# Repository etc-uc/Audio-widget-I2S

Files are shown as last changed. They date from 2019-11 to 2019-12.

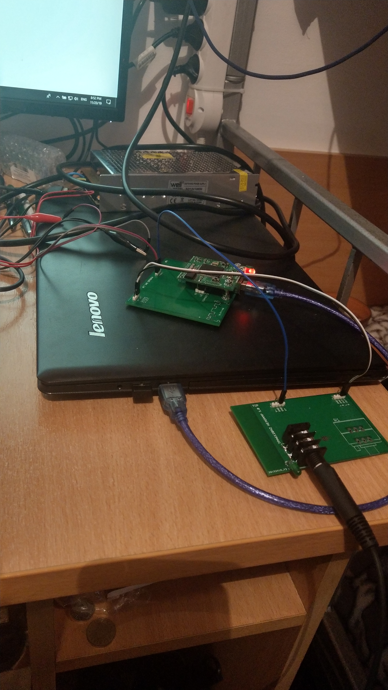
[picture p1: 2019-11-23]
IMAG1209.jpg

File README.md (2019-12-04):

# Audio-widget-I2S
**Interfata audio USB utilizand un AVR32 pe protocolul I2S**

## Introducere
>
>Inca din timpurile dinaintea erei digitale, consumatorii de audio **asa zisii audiofili** au fost in cautare de metode pentru reducerea la minim a distorsiunilor transmise catre difuzoare,si implicit,percepute de urechea umana.In vremea respectiva,data fiind si complexitatea destul de redusa a dispozitivelor,ideea reducerii distorsiunilor in sisteme era destul de limitata de topologiile propuse,de aceea aparitia sistemelor digitale de procesare in audio a dus la reducerea drastica a neajunsurilor semnalelor analogice.Pentru **puristi** , circuitele digitale si DSP-urile sunt considerate _un sacrilegiu_ adus audiofiliei,dar este unul justificat,deoarece in ciuda complexitatii mai ridicate fata de un circuit analog pur , sistemele digitale sunt mult mai eficiente fata de complementele sale,iar posibilitatea customizarii lor este foarte mare (spre deosebire de un circuit analogic unde,pentru a modifica o caracteristica trebuie regandit tot circuitul,in cazul unui circuit digital cu uC este doar o problema de software).

>Aparitia interfetelor audio s-a facut odata cu dezvoltarea PC-urilor si inregistrarea de muzica/sunete pe medii digitale , in pofida benzilor magnetice si a discurilor de vinil , deoarece era necesara o metoda de redare a sunetelor stocate pe calculatoarele vremii. De altfel,primele asa zise **placi de sunet** si-au facut aparitia prin calculatoare in jurul generatiei 80486 , cand deja exista o oarecare structura de operare stabila pe 16 biti , iar pentru o esantionare simpla a sunetelor erau arhisuficiente instructiunile implementate de Intel in procesoarele respective.
>>_Daca facem referinta la vremurile actuale,se poate spune ca practic nici nu se punea problema de calitate sau termenul de **Hi-Fi** in acele vremuri,dar acele sunete au reprezentat ceea ce urma sa fie boom-ul erei digitale_
>
>Ca si istorie a acestei ere in care traim,se pot scrie foarte multe lucruri deja cunoscute,asa ca voi incerca sa ma concentrez pe esential.

>Ideea de "calitate audio" pe digital a aparut in momentul lansarii pe piata mondiala a CD-ului (acel lucru care acum multora dintre noi ni se pare atat de outdated,ori chiar nu il mai folosim),dar el a avut cea mai mare influenta in aparitia de tehnologii de compresie si codare audio.Ca si concept,ideea de CD a aparut prin anul 1980 ,cand Philips si Sony au incheiat un parteneriat de cercetare in domeniul digital,dorindu-se un mediu de stocare unic transmisibil,care sa aibe un spatiu de stocare a informatiilor mult mai mare decat cel al dischetelor "floppy" si al benzilor magnetice,dar totusi sa nu coste cat un hard disk al vremurilor (memo: un hard disk de tip Winchester avea o capacitate de maxim 128MB , cantarea in jur de 15-20kg si era cam cat un desktop SFF actual ca dimensiuni si costa in jur de ~5.000 de dolari unul?).
>>Standardul CD a fost definitivat in jurul anului 1983,iar in urma intelegerii realizate intre cele 2 concerne se va realiza trecerea industriei audio catre acest mediu.

>Se pune problema "compresiei audio".In a nutshell,algoritmul de compresie audio se refera la un standard de scriere-redare a sunetelor pe calculatoare. Calculatoarele,la momentul respectiv avand sisteme de operare stabile precum UNIX si DOS (vorbind de anii '80,dar regula se aplica si in prezent pe sistemele actuale),pentru a reda sunetele stocate pe medii precum hard-diskul se folosesc de niste software numite **codec** .
>>Codecurile,in esenta,sunt niste pseudo-drivere pe care sistemul de operare le interpreteaza atunci cand se executa in sistem un fisier cu extensia ce corespunde codecului respectiv.
>>Adica,spre exemplu, avem un fisier cu extensia ".mp3" , SO va sti ca la instantierea acestui fisier va trebui sa apeleze un Codec LAME(Lame Ain't an MP3 Encoder - care este o derivatie imbunatatita de-a lungul anilor de diversi programatori din conceptul original gandit de institutul Fraunhofer din Germania).

>De altfel , toate procedeele de redare/compresie si extensiile de sistem au fost posibile datorita codarii PCM (Pulse Code Modulation).
PCM reprezinta transformarea semnalelor analogice in semnale digitale printr-un algoritm de esantionare constanta a amplitudinii semnalului analogic ,iar fiecare esantion este cuantizat la cea mai apropiata valoare dintr-o gama de cuante apropiate.
>>**Codarea PCM prezinta 2 proprietati ce determina calitatea conversiei semnalului original raportat la acesta : rata de esantionare a semnalului si _bit depth_,care reprezinta cantitatea de biti al fiecarui esantion realizat (un CD-Audio prezinta un bit depth de 16 biti per esantion , pe cand un Blu-ray sau DVD-Audio 24 de biti per esantion).**
>>> Extensiile posibile unei compresii PCM sunt ".wav" ,".L16",".PCM",".AIFF",".AU"

>Pe baza codarii/compresiei PCM a fisierelor audio, cei de la Philips au realizat in anul 1986 (si ulterior revizuit in 1996) un protocol de transmisie seriala al datelor audio intre dispozitive / circuite integrate , protocol care inca se foloseste cu succes si in prezent in dispozitivele audio. Este cunoscut sub acronimul I2S sau IIS **Inter-IC Sound** si se bazeaza pe o magistrala sincrona de transmisie de date (clockul de transmisie intre circuite este separat de magistrala de date,deci implicit receptorul nu mai are nevoie de un circuit suplimentar de refacere a frontului de ceas trimis de emitator).
>Protocolul este relativ usor de interpretat, in principal avem de-a face cu 3 semnale : bit clock line(**BCLK**) , word clock line (cunoscut sub denumirea oficiala de 'word select' **WS** sau 'left-right clock' **LRCLK** ) si cel putin o linie de date multiplexata **SD**

>>Adeseori se mai poate intalni peste cele 3 semnale cunoscute inca un semnal de tact (care nu face parte din protocol) cu rolul de a sincroniza operatiile interne ale DAC-urilor cu cele ale controllerului . Este gasit sub acronimul de "Master clock" **MCLK**
>>>Frecventa tipica de lucru se calculeaza dupa formula : **MCLK = 256 * LRCLK**

500px-I2S_Timing svg

###### Cum functioneaza protocolul:

>Semnalul de "Word Select" permite dispozitivului receptor sa 'vada' ce canal urmeaza sa fie trimis , deoarece I2S permite ca pe aceeasi linie de date sa fie trimise 2 canale,fiind un semnal cu factor de umplere 50% si frecventa egala cu cea de esantionare a semnalului trimis.
>>**Pentru semnale stereo , in brosura de specificatii a I2S se spune ca semnalul audio de pe canalul stang se transmite pe palierul de 0 al Word Select , iar canalul drept pe palierul de 1 . De obicei , semnalul "Word Select" este sincronizat dupa fronturile cazatoare ale semnalului BCLK , deoarece datele sunt zavorate pe fronturile crescatoare**.
>>
>Se stabileste semnul liniei de date si se codeaza in complement fata de 2 cu primul bit MSB-ul . **Acest lucru permite ca numarul de biti per cadru sa fie arbitrar , fara a fi nevoie de "negociere" intre emitator si receptor **.

## Specificatii montaj:

1.
 a)Microcontroller utilizat:  Atmel AT32UC3A3256 
 >>>  A complete system-on-chip 32-bit AVR microcontroller. It is designed for cost-sensitive embedded applications that require low power consumption, high code density and high performance.

 >>> The microcontroller's Memory Protection Unit (MPU) and fast, flexible interrupt controller support the latest real-time operating systems. Higher computation capabilities are achievable using a rich set of DSP instructions. The device incorporates on-chip flash and SRAM memories for secure and fast access. 64 KBytes of SRAM are directly coupled to the 32-bit AVR UC3 for performance optimization. Two blocks of 32 Kbytes SRAM are independently attached to the high speed bus matrix for real ping-pong management.

 >>> The microcontroller achieves exceptionally high data throughput by combining the multi-layered 32-bit AVR databus,128 KB on-chip SRAM with triple high speed interfaces, multi-channel peripheral, memory-to-memory DMA controller, high-speed USB embedded host, SD/SDIO card, MLC NAND flash with ECC, and SDRAM interfaces.

 >>> This device features 256KB internal high-speed flash and full-duplex multi-channel I2S audio interface.
 
 b) DAC utilizat: PCM5102A

 >>>The PCM510xA devices are a family of monolithic CMOS-integrated circuits that include a stereo digital-to-analog converter and additional support circuitry in a small TSSOP package. The PCM510xA devices use the latest generation of TI’s advanced segment-DAC architecture to achieve excellent dynamic performance and improved tolerance to clock jitter.

 c) Amplificator/buffer iesire folosit : TPA6120
 >>>In applications requiring a high-power output, very high fidelity headphone amplifier, the TPA6120A2 replaces a costly discrete design and allows music, not the amplifier, to be heard. The TPA6120A2’s current-feedback AB amplifier architecture delivers high bandwidth, extremely low noise, and up to 128dB of dynamic range.
 
2.Utilizeaza USB Audio Class 1 / 2.

3.Capabilitati de redare audio pana la 24bit/96kHz (bit depth / sampling rate).

4.Tensiune de alimentare: 5V (doar daca utilizam DAC-ul si interfata I2S) , +12/-12V (daca se utilizeaza si amplificatorul final)

5.Consum max: 1-1,5A (este necesara alimentare suplimentara deoarece amplificatorul final de casti se alimenteaza diferential) 

### Constructie montaj:

Contructia se bazeaza pe un design modular , iar in acest sens voi concepe intregul sistem pe 4 placi:
 - una o va constitui interfata emulatoare usb-i2s
 - o placa pentru DAC si , eventual , buffere de iesire
 - o placa pentru amplificatorul final
 - o placa pentru alimentare suplimentara

Ideea conceperii montajului intr-un sistem modular este pentru imbunatatirea "lantului" pe decursul timpului (ex. realizarea unui DAC mai performant din perspectiva SNR / PSRR sau schimbarea unei surse liniare cu una in comutatie sau adaugarea de acumulatori pentru portabilitate etc.)

De altfel,un montaj modular poate presupune o asezare mai buna in cutie si,totodata, un ecranaj mai bun al partilor **mai sensibile** fata de circuitul de alimentare.
IMAG1202
IMAG1204
IMAG1206

#### Particularitate software:

Ideea interfetei I2S este bazata pe un proiect deja existent in mediul online , anume SDR-Widget https://github.com/borgestrand/sdr-widget

Asadar hardware-ul din spatele acestui sistem a fost dezvoltat in asa fel incat firmware-ul cu care am programat AVR-ul sa fie direct compatibil.
Din punct de vedere functional, din software-ul dezvoltat in acel proiect am folosit doar mediul de comunicare audio via USB (UAC1 si UAC2) si partea de control software a volumului.

Consider ca nu este necesar sa uploadez toate sursele C pentru generarea firmware-ului , asa ca voi atasa fisierul HEX(.elf) continand versiunea stabila de firmware pentru acest sistem.

#### Programarea microcontrollerului:

Seria UC3A3 de la Atmel(Microchip-ish or whatsoever) au incarcate din fabricatie un bootloader ce contine un USB DFU(Device Firmware Upgrade).
DFU este un protocol ce se regaseste in orice tip de terminal ce are propriul sistem de operare,deoarece faciliteaza operatiunea de rescriere a software-ului deja setat in terminalul respectiv utilizand o interfata de comunicare uzuala.

De aceea , microcontrolerul pe care l-am utilizat in montaj (AT32UC3A3256) l-am programat cu doar un USB si programul ATMEL FLIP 3.4.7 , utilizand din acesta batchisp-ul (pentru ca,prin constructia sa , programul Flip nu suporta la un nivel stabil aceasta serie de uC-uri).




Nu mai pot reproduce inca o data procesul de programare (sau il voi mai face ulterior daca dezvolt un alt firmware mai performant pentru cerinta data), dar comanda de programare pe care am utilizat-o este:
**batchisp -device at32uc3a3256 -hardware usb -operation erase f memory flash blankcheck loadbuffer widget.elf program verify start reset 0**
Unde widget.elf se inlocuieste cu denumirea HEX-ului de urcat pe uC.

Dupa introducerea comenzii se executa programarea uC-ului in 11 pasi:

AT32UC3A3256 - USB - USB/DFU

Device selection....................... PASS

Hardware selection..................... PASS

Opening port........................... PASS

Reading Bootloader version............. PASS    1.0.3

Erasing................................ PASS

Selecting FLASH........................ PASS

Blank checking......................... PASS    0x00000 0x3ffff

Parsing ELF file....................... PASS    widget.elf

WARNING: The user program and the bootloader overlap!

Programming memory..................... PASS    0x00000 0x1c43f

Verifying memory....................... PASS    0x00000 0x1c43f

Starting Application................... PASS    RESET   0

Summary:  Total 11   Passed 11   Failed 0

Dupa programarea uC-ului calculatorul "teoretic" ar trebui sa il recunoasca automat si sa instantieze driverul necesar utilizarii acestuia. Cel putin in Windows 10 nu exista probleme de compatibilitate a driverelor, recunoscandu-le automat la conectarea interfetei. Posibil sa existe probleme de "backwards compatibility" a firmware-ului cu versiunile mai vechi de Windows,dar se rezolva instaland manual "inf drivers".

## Utilizare:

Asio_logo

Ca si software , interfata este gandita destul de simplist,deoarece se considera ca este suficient doar un control al volumului,niciun fel de egalizare grafica sau corectie de tonuri.
Software-ul de control este scris pe framework-ul ASIO (_Audio Stream Input-Output_).
Ca si un mic memo : ASIO este un protocol de drivere open-sourced pentru "sound card-uri" specificat in industria audio de firma Steinberg.
Ca si functionare a protocolului : ASIO produce un bypass al caii audio normale la nivel de aplicatie din sistemul de operare utilizat,astfel incat sa se evite "layer-ele" suplimentare la nivel de software.Acest lucru permite aplicatiei sa se conecteze la sound card direct,fara intermedierea sistemului de operare in procesul respectiv.Acest lucru duce la o reducere foarte mare a latentei de transfer a informatiei audio de la soft la hard.

Foobar2000_logo_2014

>>Foobar2000 **logo de mai sus** este un player audio freeware (nu este necesara licenta de utilizare) pentru Microsoft Windows, iOS, si Android dezvoltat de Peter Pawłowski.Ca si software este cunoscut designul sau extrem de modular , multitudinea de caracteristici si flexibilitatea in configurare pentru user.
>>Acest player suporta foarte multe formaturi audio , prezinta o multitudine de caracteristici organizarea fisierelor , metadata si are implementata o interfata de convertor utilizabila in linie de comanda (transcodare fisiere si ripping CD-Audio). 



In poza , aplicatia redand un fisier audio .FLAC (lossless audio codec) , configurat pentru output pe WASAPI* , buffer length minim pentru jitter scazut intre interfata de comunicare si controller.

>>>> **Ca si ASIO , WASAPI (Windows Audio Session API) este un plugin utilizat in audio pentru a permite trecerea fluxului de date audio direct intre terminalul audio din aplicatia ce reda fisierele audio**
>>>> Diferenta principala dintre ASIO si WASAPI este ca , primul este un plugin open-source (poate fi luat si modificat in drivere de oricine) , pe cand cel din urma este conceput de MICROSOFT si na...copyright in a nutshell daca vrea cineva sa modifice core-ul plugin-ului.



>>>Ca si comparatie intre cele 2 pluginuri, ambele sunt foarte usor de utilizat si instalat , cu precizarea ca ASIO functioneaza cu doar cu dispozitivele ce au descriptori dedicati in driverele lor , pe cand WASAPI functioneaza cu orice fel de endpoint device , atata timp cat este selectat pluginul ca si output pentru device-ul respectiv si nu adresa "Direct Sound".

>>>> **De precizat ar mai fi ca,atata timp cat un eveniment WASAPI / ASIO este executat , nu se mai reda niciun flow audio din partea altor aplicatii pana nu se incheie evenimentul respectiv**

### Ansamblare

Pentru incapsularea proiectului am ales sa separ sursa de alimentare de partea de DAC+Amplif casca pentru a evita producerea de zgomot inutil in sistem. **ideea este tocmai de a avea un zgomot minim in tot lantul si atunci este de preferat ca sursa sa stea cat mai departe de elementele sensibile ale sistemului**

Asadar , pentru incapsularea amplificatorului am comandat o carcasa din aluminiu eloxat argintiu de la Hammond,cu dimensiunile 220x103x31mm (LxlxH) , iar pentru sursa probabil voi utiliza o cutie de ramificatie electrica **de aparataj** pentru ca nu are prea mare importanta aspectul ei (ca oricare alta sursa de alimentare, va sta intr-un loc prea putin vizibil).



Pentru alimentare voi monta pe ambele carcase o mufa DIN 3P ce se asigura cu o piulita de blocare , cu 3 pini deoarece amplificatorul se alimenteaza diferential.

#### Masuri pentru evitarea producerii/captarii de zgomot in circuit:

1.Decuplarea alimentarilor cu condensatoare de valoare foarte mica (capabilitate de lucru in frecvente mari) - zeci/sute nF si de valoare f. mare (capabilitate de lucru in frcvente mici).

2.Torsadarea cablurilor de alimentare din carcasa (reducerea emisiilor em. in circuit).

3.Separarea pe cat posibil a circuitelor de semnal mic fata de cele de alimentare.

4.Utilizarea unui punct comun de legatura a maselor din intregul circuit (star pattern sau line pattern , in cazul meu voi utiliza un line pattern deoarece nu sunt implicati curenti mari de circuit - max 1A peak).

5.Utilizare de filtraj cat mai generos - capacitatile mari de filtrare implica un riplu foarte mic al sursei de alimentare,deci posibilitatea aparitiei unui zgomot perturbator pe alimentare minim.
>>Cu riscul aparitiei unui curent de incarcare foarte mare,se recomanda utilizarea de capacitati mari pentru evitarea riplului,mai ales in circuite unde este nevoie de curenti mari pe perioade scurte.
>>>Problema curentilor mari de incarcare se rezolva cu niste rezistente serie cu condensatorii (zeci de ohmi),care sa limiteze curentul prin ei la pornire,dupa aceea rezistentele se sunteaza cu un releu si se utilizeaza normal **soft-start empiric**

**RIPLU -> componenta alternativa aparuta la ciclurile de incarcare-descarcare ale condensatorilor intr-un redresor**

## Limitari si probleme aparute de-a lungul constructiei:

Cea mai mare problema am avut-o la ansamblare...un cosmar si jumatate din perspectiva unei persoane ce a lucrat mai tot timpul cu componente THT si acum s-a lovit de "zidul" lipirii de componente SMD. Am facut si prostia de a ma apuca si fix de cea mai complicata placa mai intai , cea a interfetei USB-I2S, cei 144 de pini ai uC-ului mi-au dat de furca pana l-am lipit cum trebuie,deoarece m-am incapatanat sa il lipesc pin cu pin cu letconul si la un moment dat aveam efectiv mai multe scurturi intre pini decat pini lipiti cum trebuie de placa.Dar acest mic detaliu a fost rezolvat cu mult flux,efect capilar si injuraturi cand nu voia fludorul sa plece dintre pini pe talpa varfului folosit.
De altfel ,toate componentele 0603 de pe aceasta placa mi-au provocat o mare placere de a invoca sfinti de-a lungul lipirii lor.
Apexul a fost atins la ora 3 noaptea,dupa ce am terminat de lipit placuta interfetei,am legat-o la USB si am realizat,cu stupoare,ca nu face nimic...nu se conecta la calculator.Din nou,nervi injuraturi,abtineri din a tranti minunea peste tot.
A doua zi am rezolvat problema in 10 minute : stabilizatorul 5V-3.3V de pe placa avea un pin " in aer " si nu aveam output pentru alimentarea uC-ului.

**Morala ar fi ca: prea multe beri si oboseala dupa 12 ore de alergat dintr-o parte in alta dauneaza bunei atentii asupra realizarii unui montaj.**

Montarea placii DAC a fost pretty straightforward , nu am intampinat cine stie ce dificultati, mai ales acum avand experienta lipirii "ghindoacelor" 0603 pe placa interfetei ... componentele 1206 si integratul SSOP cu 20 de pini au fost PARFUM!!

Placa amplificatorului am montat-o si cam atat, pana acum m-am folosit doar de mufa de casca pentru a vedea daca functioneaza dacul cum trebuie.Urmeaza sa montez si sursa de alimentare si o voi testa si pe aceasta.

Singura limitare "constructiva" mi-am creat-o singur,din pricina carcasei alese pentru circuit. Am ales o carcasa cu inaltimea de 31mm, insuficient pentru inaltimea potentiometrului pe PCB-ul amplificatorului.Am fAacut aceasta eroare deoarece nu am tinut cont ca primele caneluri de suport pentru cablaje incep de la aproximativ 5mm fata de fundul carcasei , ceea ce ar insemna ca depasesc inaltimea montarii capacului cu potentiometrul cu vreo 2mm din ce am masurat.

Solutia: montat potentiometrul si mufa de casca solitare pe panoul frontal si facut legaturi cu PCB-ul prin cabluri torsadate si mufate.

## Constructie sursa de alimentare

Cel mai mare semn de intrebare posibil din tot proiectul ce se putea pune : Ce sursa de alimentare sa folosesc , liniar sau comutatie? Cum naiba fac sa nu stric tot "zenul" montajului cu zgomote inutile aduse de catre o sursa?

De altfel, orice sursa as alege inevitabil tot ma aleg cu un oarecare zgomot in circuit,pentru ca nu poti elimina o cauza fara a genera un alt defect.

Solutia : **in mintea mea** 

Se da o sursa clasica stabilizata , realizata extern circuitelor de semnal / amplificat. Sursa o voi realiza cu un transformator incapsulat in rasina de 10-15VA,deoarece nu am nevoie de foarte multa putere de iesire. Redresare cu punte de diode clasise / schottky (inca nu m-am decis daca se merita efortul pentru diode schottky,mai ales pentru frecventa retelei).

Filtraj inainte de stabilizare 2x4700uF + decuplarile de rigoare pe diode cu 100nF + 220-470nF in bratul stabilizatorului + buffer suplimentar de curent dupa stabilizatoare 2x4700uF + 100nF. Bufferul il voi amplasa in carcasa interfetei,pentru a realiza si punctul comun de legatura al masei pentru tot circuitul.

Imi asum riscul ca voi avea un curent initial de incarcare enorm pentru acel transformator (10000uF insumati pot produce un oarecare deranj mai ales pentru o sursa ce nu debiteaza un curent foarte mare),dar acest lucru il voi vedea exact cand voi finaliza si acest pas.

Stabilizatoarele probabil vor fi clasicele 7812/7912 (not so many fancy things there , sursa trebuie sa fie cat mai simpla si eficienta,fara prea multe briz-briz-uri).

## Final updates

1. La indemnul tatalui meu am achizitionat inca o carcasa de la Hammond , "sora" celei pe care am prezentat-o mai sus , din pricina incapsularii tuturor modulelor intr-un singur loc si nu "in o mie si una de cutiute". Ca si forma sunt identice,singura diferenta o face inaltimea lor (31mm vs 53mm).

2. Am ansamblat sursa de alimentare *dupa lupte seculare as putea spune* si am descoperit ca pentru ce am eu nevoie 4700uF pe brat de alimentare este mai mult decat suficient.Dupa cum ma asteptam , folosind pattern-ul line pentru legarea maselor la comun si decuplarea "sanatoasa" a elementelor sursa nu induce zgomot in circuite...great succes i would say :)
Singura problema: am facut-o pe cablaj de test pentru ca nu am mai avut rabdare sa corodez o foaie de cablaj ... but not so much of a thing pentru ca am tinut cont de dimensionarea corecta a traseelor de circuit si pozitionarea elementelor disipatoare de caldura astfel incat circuitul sa nu se degradeze rapid,dar totusi sa fie compact si sa se incadreze in aria necesara.

3. Odata cu sursa,am testat intr-un final si amplificatorul final si pot spune ca a meritat asteptarea...chiar suna foarte bine in combinatie cu dacul facut.Imi era foarte teama de imperecherea lor,dar a fost doar paranoia si atat.

Dar credeti ca am scapat de peripetii? Nicio sansa, la prima "cheie" amplificatorul nu a vrut sa cante nici sa-l fi batut.
Am incercat sa elimin toate posibilele cauze , in prima instanta am inlocuit toate cablurile de legatura dar degeaba ca tot nu a vrut sa mearga. Am sucit sursa pe toate partile,am zis ca poate am legat ceva prost pe acolo,dar nicio sansa,toate legaturile erau facute bine si aveam tensiune aproape egala pe ambele brate de alimentare.Ce mama masii sa mai aiba si placa asta acum?!
Am legat dacul direct la iesirea de casti si aveam semnal redat,deci nicio sansa sa fie din alta parte problema.
Deschid schema , stau si ma uit la layoutul cablajului si dupa realizez ca integratul meu amplificator este montat invers pe pcb ... #$%^#$$@$^$%^#$#@%#$^ masii de treaba. Tuff job de dezlipit din cauza fludorului ce tine padul de disipatie termica lipit de cablaj.Din nou,sfinti,altare si tot tacamul pana l-am dezlipit si relipit (noroc cu colegul de camera muuuultt mai rabdator decat mine).
Dupa ce l-am relipit zeii siliciului au decis sa nu imi arda integratul si l-am putut auzi cantand, finally . Intr-un final , tot lantul meu audio este gata si functional, iar singurul lucru ce mi-a mai ramas de facut este sa gauresc panoul frontal si sa strang ultimele 4 suruburi de pe cutie :)

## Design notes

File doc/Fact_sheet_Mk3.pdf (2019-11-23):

Henry Audio

fact_sheet_Mk 3.pdf | BSB – 20180811
1

## 1. Introduction

This document is intended for everybody who wishes to use or investigate the Henry Audio USB DAC 128 Mk 3 and its predecessors (Henry Audio USB DAC 128 USB DAC 128 mk II, QNKTC AB-1.2, AB-1.1 and AB-1.0). The schematics for all these products are Open Source!

Programmers and developers should also read the complete project readme file at https://github.com/amontefusco/sdr-widget/blob/audio-widget-experimental/AW_readme.txt

For commercial reuse of the technology behind Henry Audio's products you should contact borge@henryaudio.com

The contents of this file are:

## 2. Technical Specifications

The USB DAC 128 Mk 3 plugs in between your computer and an audio amplifier. It will work on Linux, Mac and Windows. With a powered USB hub and an on-the-go cable it will also work on Android and iOS devices. High resolution audio is not guaranteed on Windows XP.

The electrical design focuses on high quality circuit board layout and good components.

Some technical details:

- A fully assembled, tested and packaged DAC which plays music out of the box
- Asynchronous USB Audio powered by Golledge high-quality crystal oscillators at 22.5792 and 24.576MHz
- Supports the common sample rates of 44.1, 48, 88.2, 96, 176.4 and 192ksps

Henry Audio

2

- RCA (phono) stereo outputs
- Asahi Kasei AKM4430 DAC
- Atmel AVR32 general-purpose MCU programmed in open source C
- ASIO driver for Windows programmed in open source C
- Low-noise 3.3V ADP151 LDOs powered from USB. No external power supply.
- The option of experimenting with the power supply.
- Lots of internal headers for experimenting.
- You must provide a USB 2.0 type-B cable. This is the same kind of cable as is typically used with a printer. It is not included. Use a cable shorter than 3m.
- Mechanical size: W: 114.4mm, H: 32.8mm, D: 119mm.
- Computer requirement: The DAC will work on well on all modern computers. The DAC may not work well on computers with processors below the performance of a Core 2-duo / 2GHz CPU. USB Audio Class 2 drivers may not work on Windows XP.

## 3. USB Audio Class 1 & 2

USB Audio has two different ways to communicate with the computer, USB Audio Class 1 and 2. The USB DAC 128 Mk 3 will operate in both UAC1 and UAC2.

The reason for supporting two modes is that only UAC1 is supported by all operating systems, including Windows.

UAC2 is needed for high resolution playback. Windows 10 supports UAC2. Earlier versions of Windows (7, 8, XP) need a special driver to work with UAC2. See the next sections of this document. When the DAC is first powered on it will use UAC1. That way it will work right out of the box on all computers, and the playback will have more than CD quality.

Windows 10, OS X, Linux, iOS and Android support both UAC1 and UAC2 natively. On those systems you may as well select UAC2 as you start using your new DAC.

UAC1 is more than enough if the music you play was once on a CD. The Henry Audio USB DAC 128 Mk 3 supports up to 24 bit / 48ksps in UAC1. That is more than sufficient for ripped CDs or streaming.

Henry Audio

3

UAC1 is indicated by a green light at the front of the USB DAC 128 Mk 3. UAC2 is indicated by a red light. To switch between the two modes do as follows:

- Press the rear Prog button until the light changes
- Keep pressing Prog until the light goes dark
- Press and release Reset

## 4. Asynchronous USB Audio

The USB audio protocol is asynchronous with both UAC1 and UAC2. That means the analog part of the DAC minimizes jitter errors.

What does asynchronous USB mean? It means the DAC is the timing master. In typical digital audio based on S/PDIF (coax) and TOSLINK (optical) cables the audio data and the clock are synchronous. Both travel from the same source. This source is typically a CD drive. Such a drive may or may not be made with a good internal clock circuit.

Synchronous digital audio is also common over USB. Then the timing reference is derived inside the computer. That clock is often very noisy. With synchronous digital audio the DAC is responsible for extracting the clock signal.

Instead, with an asynchronous protocol, the source of the audio data becomes the timing slave. Commands are sent on the USB cable from the DAC to tell the computer to speed up or slow down. This enables the DAC to use precision crystal oscillators instead of a complex clock regenerator. The audible result is that many of the typically digital artifacts are significantly reduced.

## 5. Disabling resampling

Most modern operating systems, except for iOS, will automatically resample your digital music as it is being played back. This is not a major issue, but it may improve sound quality to turn it off. Some player programs disable resampling on their own. On Windows using the protocols WASAPI or ASIO disables resampling.

Because most digital music is recorded at the CD's sample rate of 44.1ksps, you are recommended to set this as the default sample rate for the DAC.

Linux and MPD
If you use Linux and MPD make sure you enter the following line in the audio_output section of your .mpdconf file:
auto_resample "no"

Henry Audio

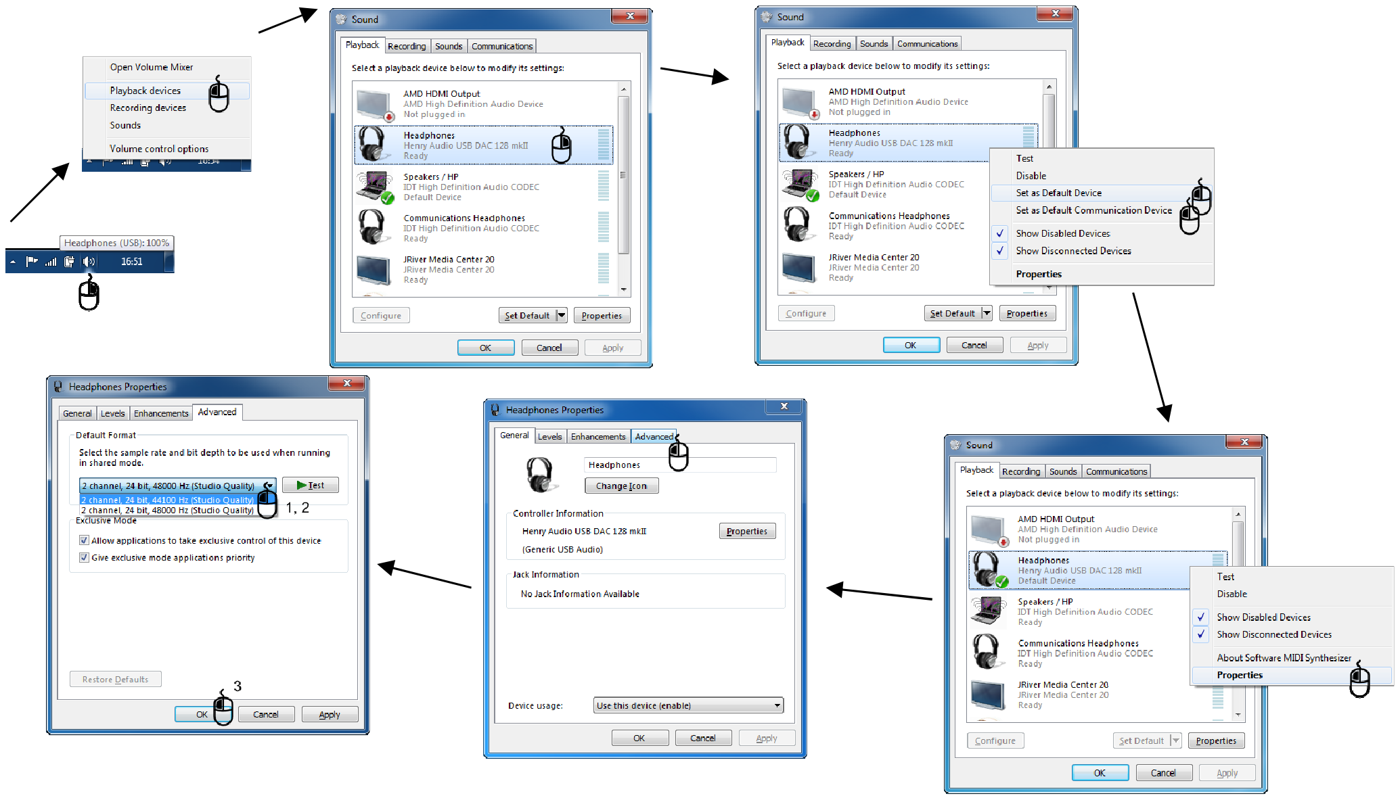
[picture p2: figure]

4

This will disable resampling, and you don't need to set a default rate.

OS X
In OS X the sample rate setting for a DAC is set in the "Audio MIDI Setup". Look for this icon under Applications, Utilities:

The 44.1ksps setting is the best way to use generic Mac programs to play back music which was once stored on a CD. It is also the recommended setting for streaming music from the internet.

For playback of hi-res material, make sure that your player program is able to override the sample rate setting of OS X.

NB: On your Mac you should set the default sample rate to 44.1ksps for both UAC1 and UAC2 configurations of the DAC. That is because your computer will recognize those as two different DACs.

Windows 7
On Windows you can only set the default sample rate to 44.1ksps when the DAC is in UAC1 mode. In UAC2 mode, with the ASIO driver, there is no need to do this. Follow these steps to set the sample rate:

Henry Audio

5

Windows 10
The menu structure in Windows 10 is slightly different:

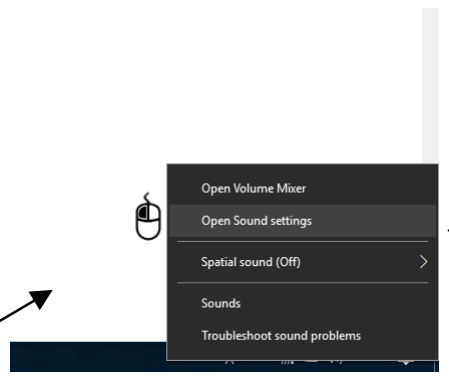
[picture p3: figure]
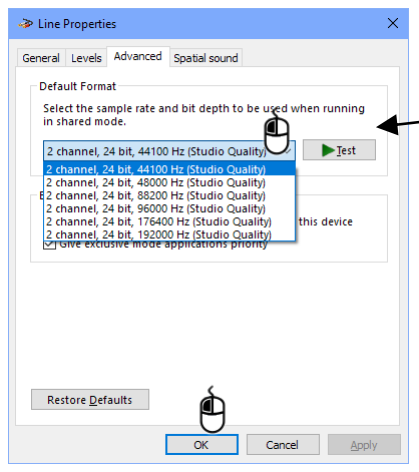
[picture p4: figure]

## 6. Installation on Windows

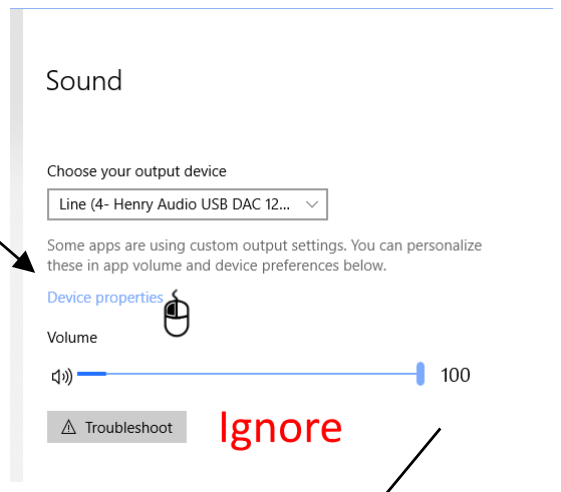
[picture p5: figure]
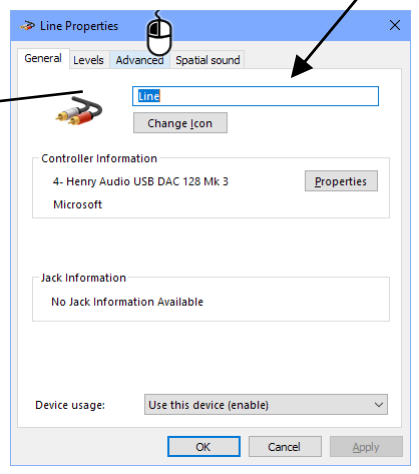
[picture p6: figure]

Windows 10 needs no special attention to make the DAC work for hi-res music. Both UAC1 and UAC2 drivers come pre-shipped with the operating system, and you can enjoy high resolution music from all Windows programs.

Do you use Windows 7 or Windows 8? In that case there is no built-in support for USB Audio Class 2, and you will have to choose between two ways to use the DAC:

Option 1: Use the DAC as it is delivered and listen to music at (or slightly above) CD quality from all Windows programs. To do this you need NO driver installation and NO button presses on the DAC.

Option 2: Use the DAC in USB Audio Class 2 mode with an ASIO driver. This option enables hi-res music and sample rates up to 192ksps on Windows 7 and Windows 8 computers. On these computers, such resolution is only available in ASIO enabled player programs. Please note: When used in UAC2 on Windows 7 and Windows 8, the DAC will NOT appear as an ordinary sound card.

Henry Audio

6

Follow these steps to install the hi-res ASIO driver for the USB DAC 128 Mk 3 on a Windows 7 or 8 computer. Windows XP functionality is not guaranteed.

1. Do not plug in the USB DAC 128 Mk 3 yet.

### 2. If you have an earlier version of the driver installed, first follow the uninstall

instructions later in this text.

### 3. Download and install the driver from

https://github.com/borgestrand/widget_binaries/blob/master/AWSetup_20130211.zip

### 4. Answer Yes and OK to all questions. You may have to approve that an

unsigned driver may be installed.

### 5. Put the DAC into UAC2 mode according to section 3. The first time you

change modes, Windows may have to install additional drivers. It should be able to do that fully automatically.

## 7. Setup with JRiver Media Center

The JRiver Media Center is a powerful media playback program. It offers a 30-day free use and after that must be paid for. The license cost is currently USD 50.

After following the steps on driver installation do as follows:

### 1. Download and install Media Center from http://www.jriver.com/download.html

### 2. Plug in the USB DAC 128 Mk 3

### 3. Given 5 minutes or less, Windows should be able to find and install all drivers

J-River Media Center is set up to use the default sound output device. Here is how to set it up to use the USB DAC 128 Mk 3 to listen to hi-res music.

### 1. First do as above to select UAC2 and a red front LED color

### 2. Start J-River Media Center

### 3. Click the top-right bars icon:

### 4. In the Tools window choose Playback Options:

### 5. In the Options window choose according to your operating system. On

Windows 10 choose “Henry Audio USB DAC 128 Mk 3 – WASAPI”. On Windows 7 and 8 choose “ASIO”:

Henry Audio

7

### 6. Click Output Mode Settings:

### 7. On Windows 10 do nothing. On Windows 7 and 8 go to the ASIO Settings

window choose Device = ASIO UAC2:

### 8. Click OK in all windows to close them

### 9. Use the file menu to open up your music files and play them

NB: ASIO drivers are shown on the pull-down menu even if the DAC served by the driver the listed driver is not plugged in.

## 8. Setup with foobar2000

foobar2000 is a free music playback program for Windows. It has good ASIO integration and some strong features.

After following the steps on driver installation do as follows:

### 1. Download and install foobar2000 from http://www.foobar2000.org/download

### 2. On Windows 7 and 8 download and install the foobar2000 ASIO plug-in from

http://www.foobar2000.org/components/view/foo_out_asio. The ASIO plug-in installation will reconfigure and restart foobar2000. On Windows 10 there is no need to install ASIO. Feel free to experiment with the WASAPI plugin, though.

### 3. Plug in the USB DAC 128 Mk 3

### 4. Given 5 minutes or less, Windows should be able to find and install all drivers

foobar2000 is set up to use the default sound output device. Here is how to set it up to use the USB DAC 128 Mk 3 with UAC2. This will enable you to listen to hi-res music.

### 1. First do as above to select UAC2 and a red front LED color

### 2. Start foobar2000

Henry Audio

8

### 3. Click "File" and then "Preferences"

4. Expand "Playback" and under it expand "Output".

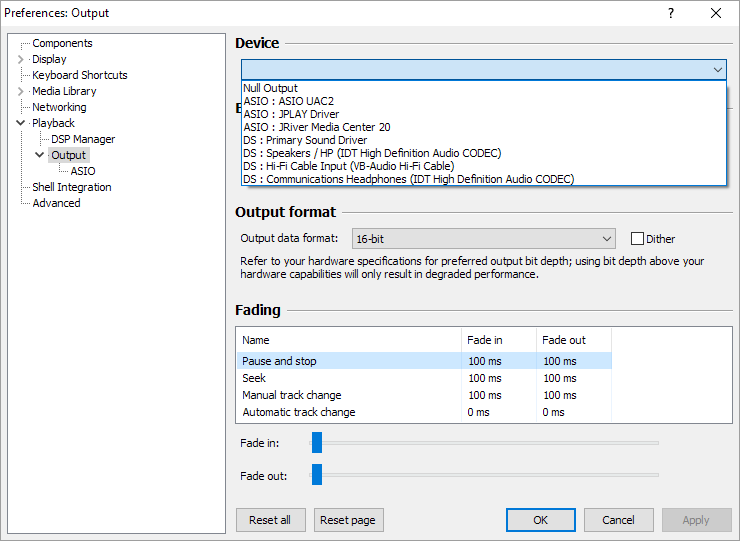
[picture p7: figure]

### 5. On Windows 7 and 8 go to the Device pull-down menu and select "ASIO

UAC2". Under "Output" in the left-hand menu click "ASIO". Make sure that "Use 64-bit ASIO drivers" is not selected.

### 6. On Windows 10 go to the Device menu and choose “Henry Audio USB DAC

128 Mk 3”

7. Click OK.

### 8. Your music should now come out of the Henry Audio USB DAC 128 Mk 3

NB: ASIO drivers are shown on the pull-down menu even if the DAC served by the driver is not plugged in.

## 9. Windows Uninstall Procedure

This text applies if you have installed an UAC2 ASIO driver and wish to remove it. Do that if you accidentally installed it on Windows 10, or if you wish to re-install it.

### 1. Unplug the USB DAC 128 Mk 3

Henry Audio

9

### 2. Uninstall Audio-Widget in Start menu or C:\Program Files (x86)\Audio-

Widget

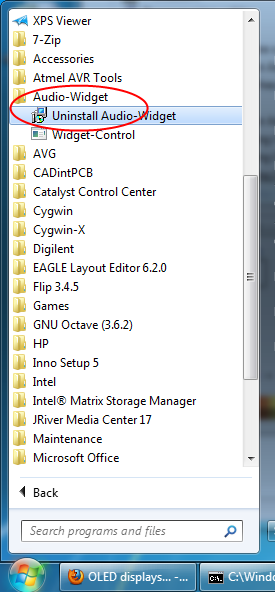
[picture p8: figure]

### 3. Open the Start menu and type in "cmd". On the icon on top, right-click and

choose "Run as Administrator". Click "OK" in the User Account Control window.

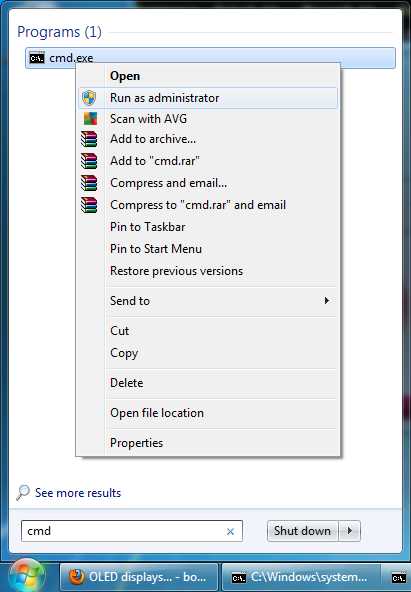
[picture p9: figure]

### 4. At the command prompt, type in "set devmgr_show_nonpresent_devices=1"

and press Enter. See next picture.

Henry Audio

10

5. On the next command prompt line, type "devmgmt.msc" and press Enter. This will launch the Windows Device Manager Console.

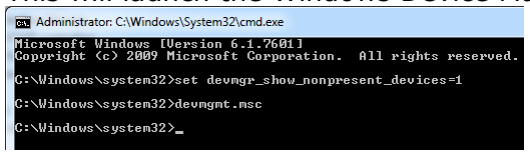
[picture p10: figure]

### 6. In the Device Manager Console, from the View menu, select

"Show Hidden Devices".

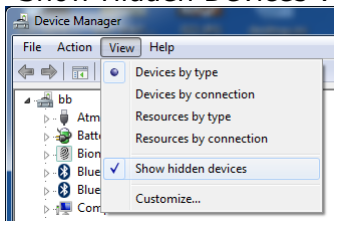
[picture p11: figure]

### 7. Search under tabs for

"libusbK USB Devices", "Sound, video...", "Audio-Widget...", "UAC2..."

Under all those tabs, delete and uninstall all drivers and anything resembling:
"Audio-Widget", "SDR-Widget", "DG8SAQ", "QNKTC", "Henry Audio", "Yoyodyne", "UAC2"

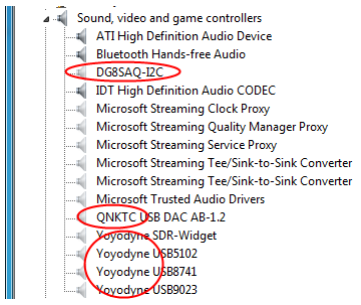
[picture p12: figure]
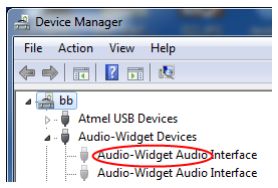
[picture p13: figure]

### 8. You should now be ready to install the new fresh version of the drivers as

shown in the previous section.

Henry Audio

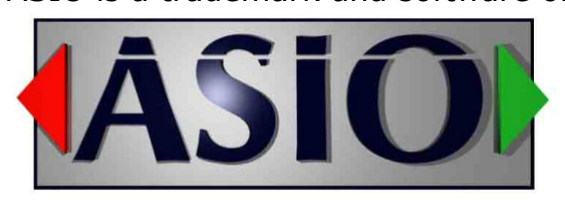
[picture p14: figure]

11

## 10. Schematic Files

The schematics of the USB DAC 128 Mk 3 are appended to this document. They are part of the open source Audio Widget project.

USB DAC 128 Mk 3 schematics by Henry Audio / Børge Strand-Bergesen is licensed under a Creative Commons Attribution-ShareAlike 4.0 International License.

Based on a work at http://www.henryaudio.com/uploads/fact_sheet_Mk 3.pdf and SDR Widget BETA 2.0 by George Boudreau.

ASIO is a trademark and software of Steinberg Media Technologies GmbH.

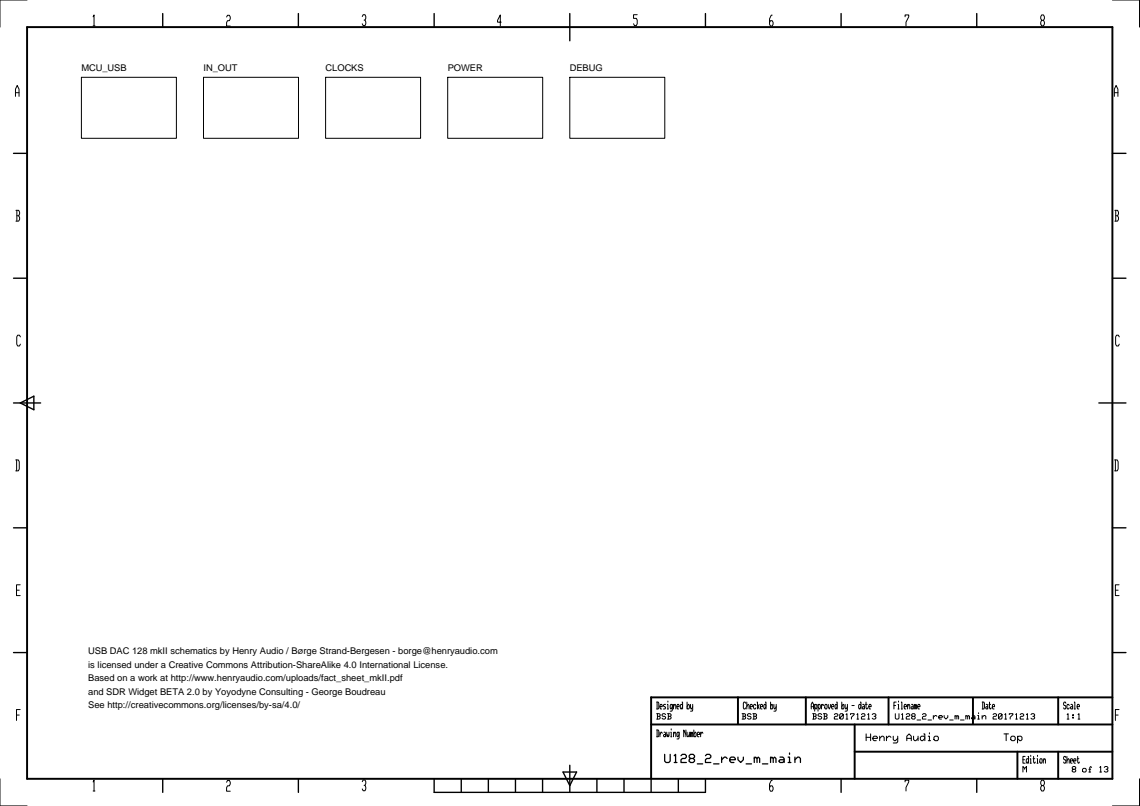
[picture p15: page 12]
MCU_USB; IN_OUT; CLOCKS; POWER; DEBUG

USB DAC 128 mkII schematics by Henry Audio / Børge Strand-Bergesen - borge@henryaudio.com
is licensed under a Creative Commons Attribution-ShareAlike 4.0 International License.
Based on a work at http://www.henryaudio.com/uploads/fact_sheet_mkII.pdf
and SDR Widget BETA 2.0 by Yoyodyne Consulting - George Boudreau
See http://creativecommons.org/licenses/by-sa/4.0/

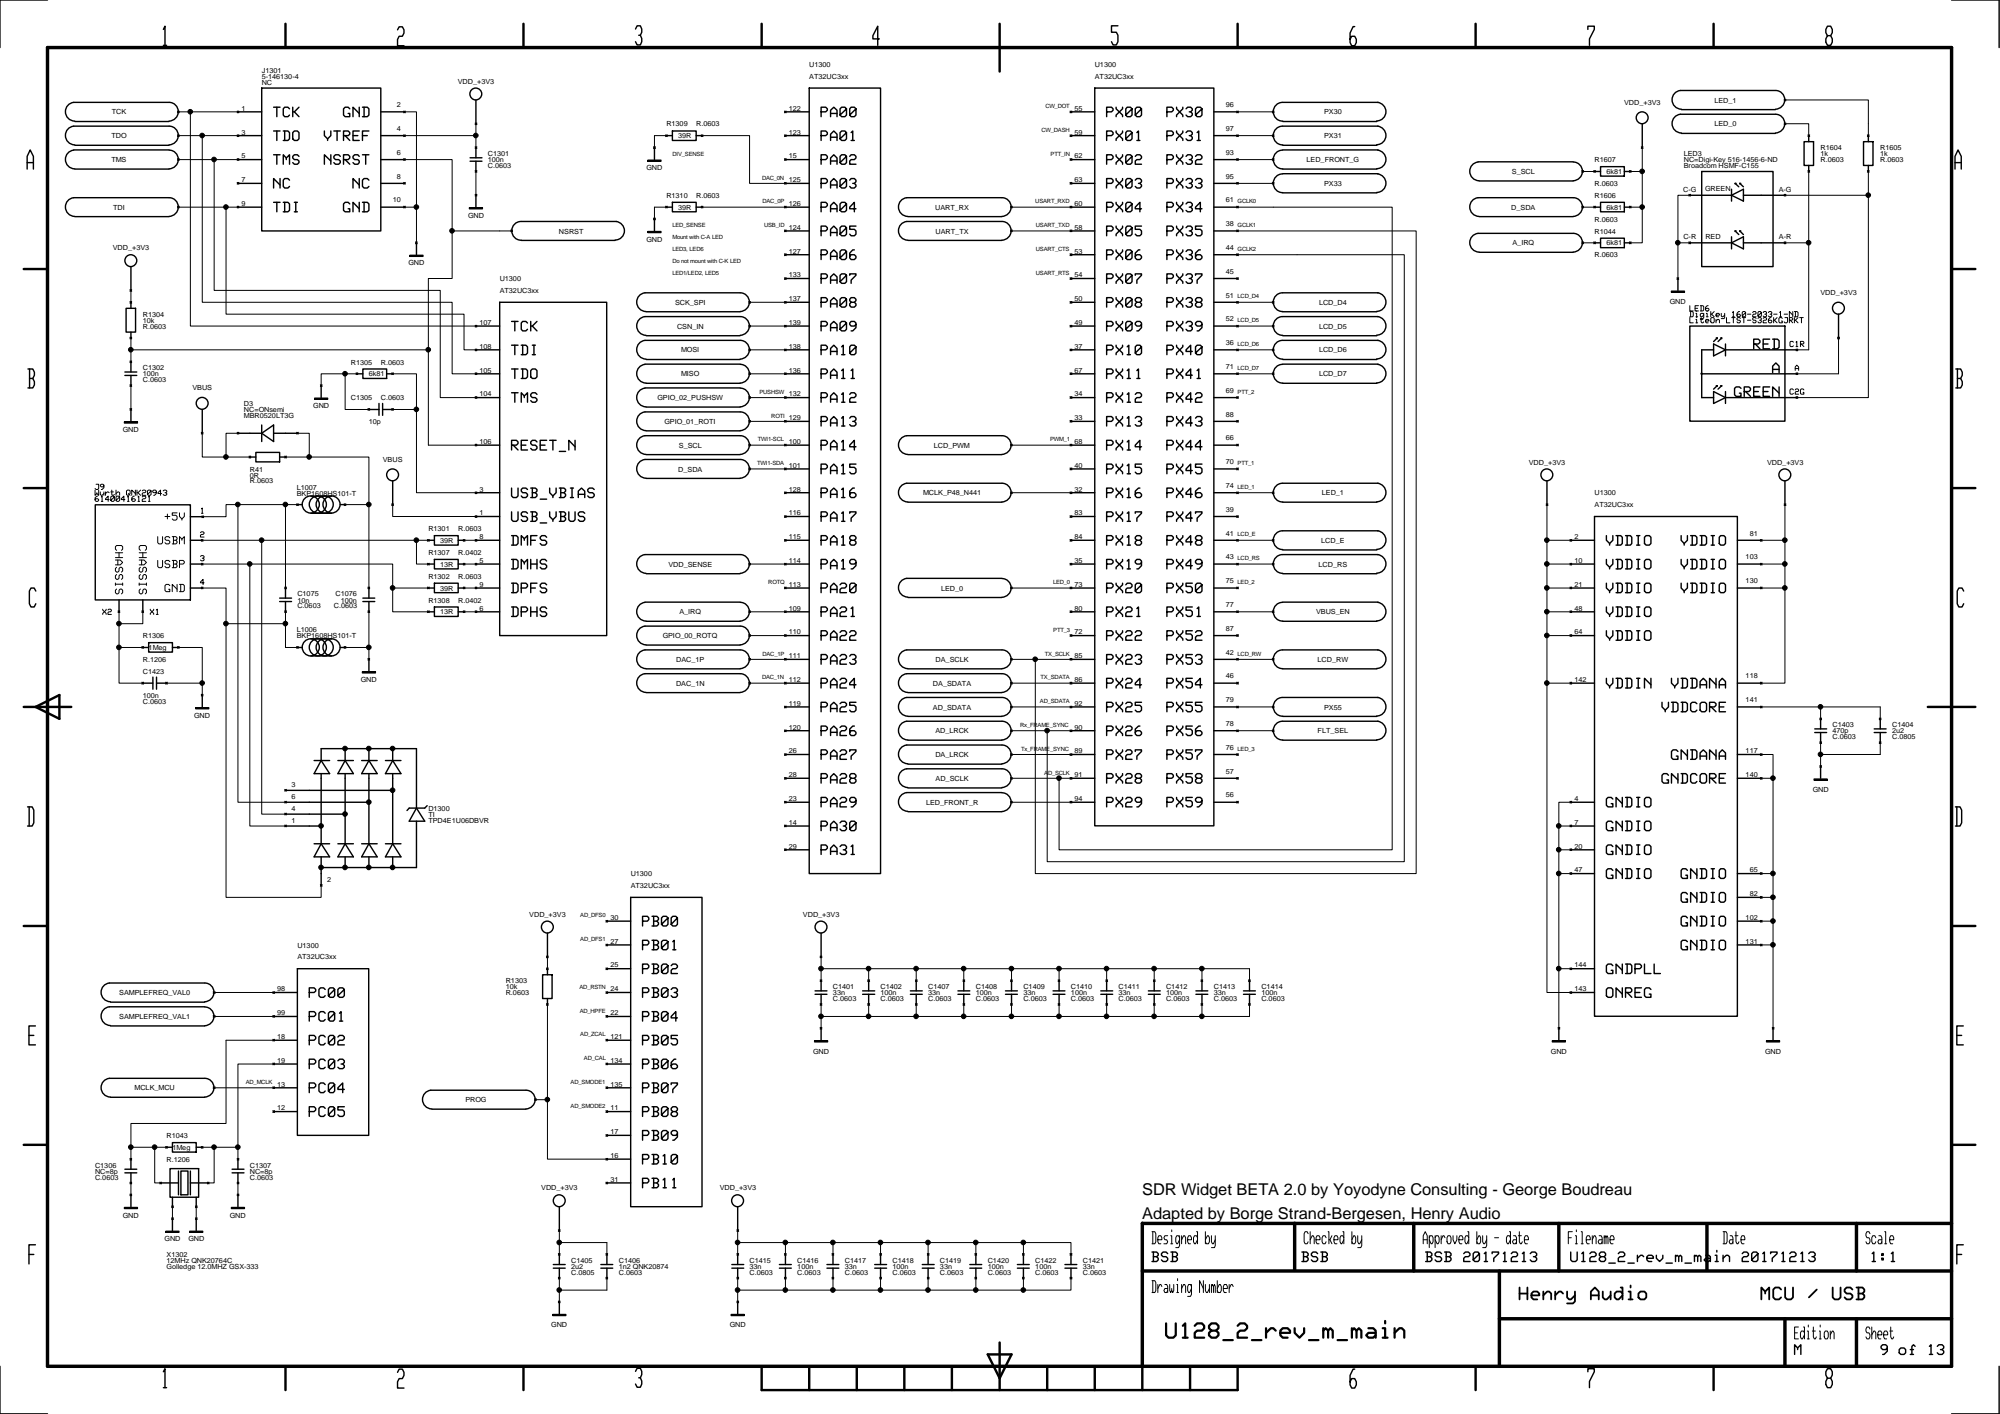
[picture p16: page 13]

LED3
NC=Digi-Key 516-1456-6-ND Broadcom HSMF-C155

SDR Widget BETA 2.0 by Yoyodyne Consulting - George Boudreau
Adapted by Borge Strand-Bergesen, Henry Audio

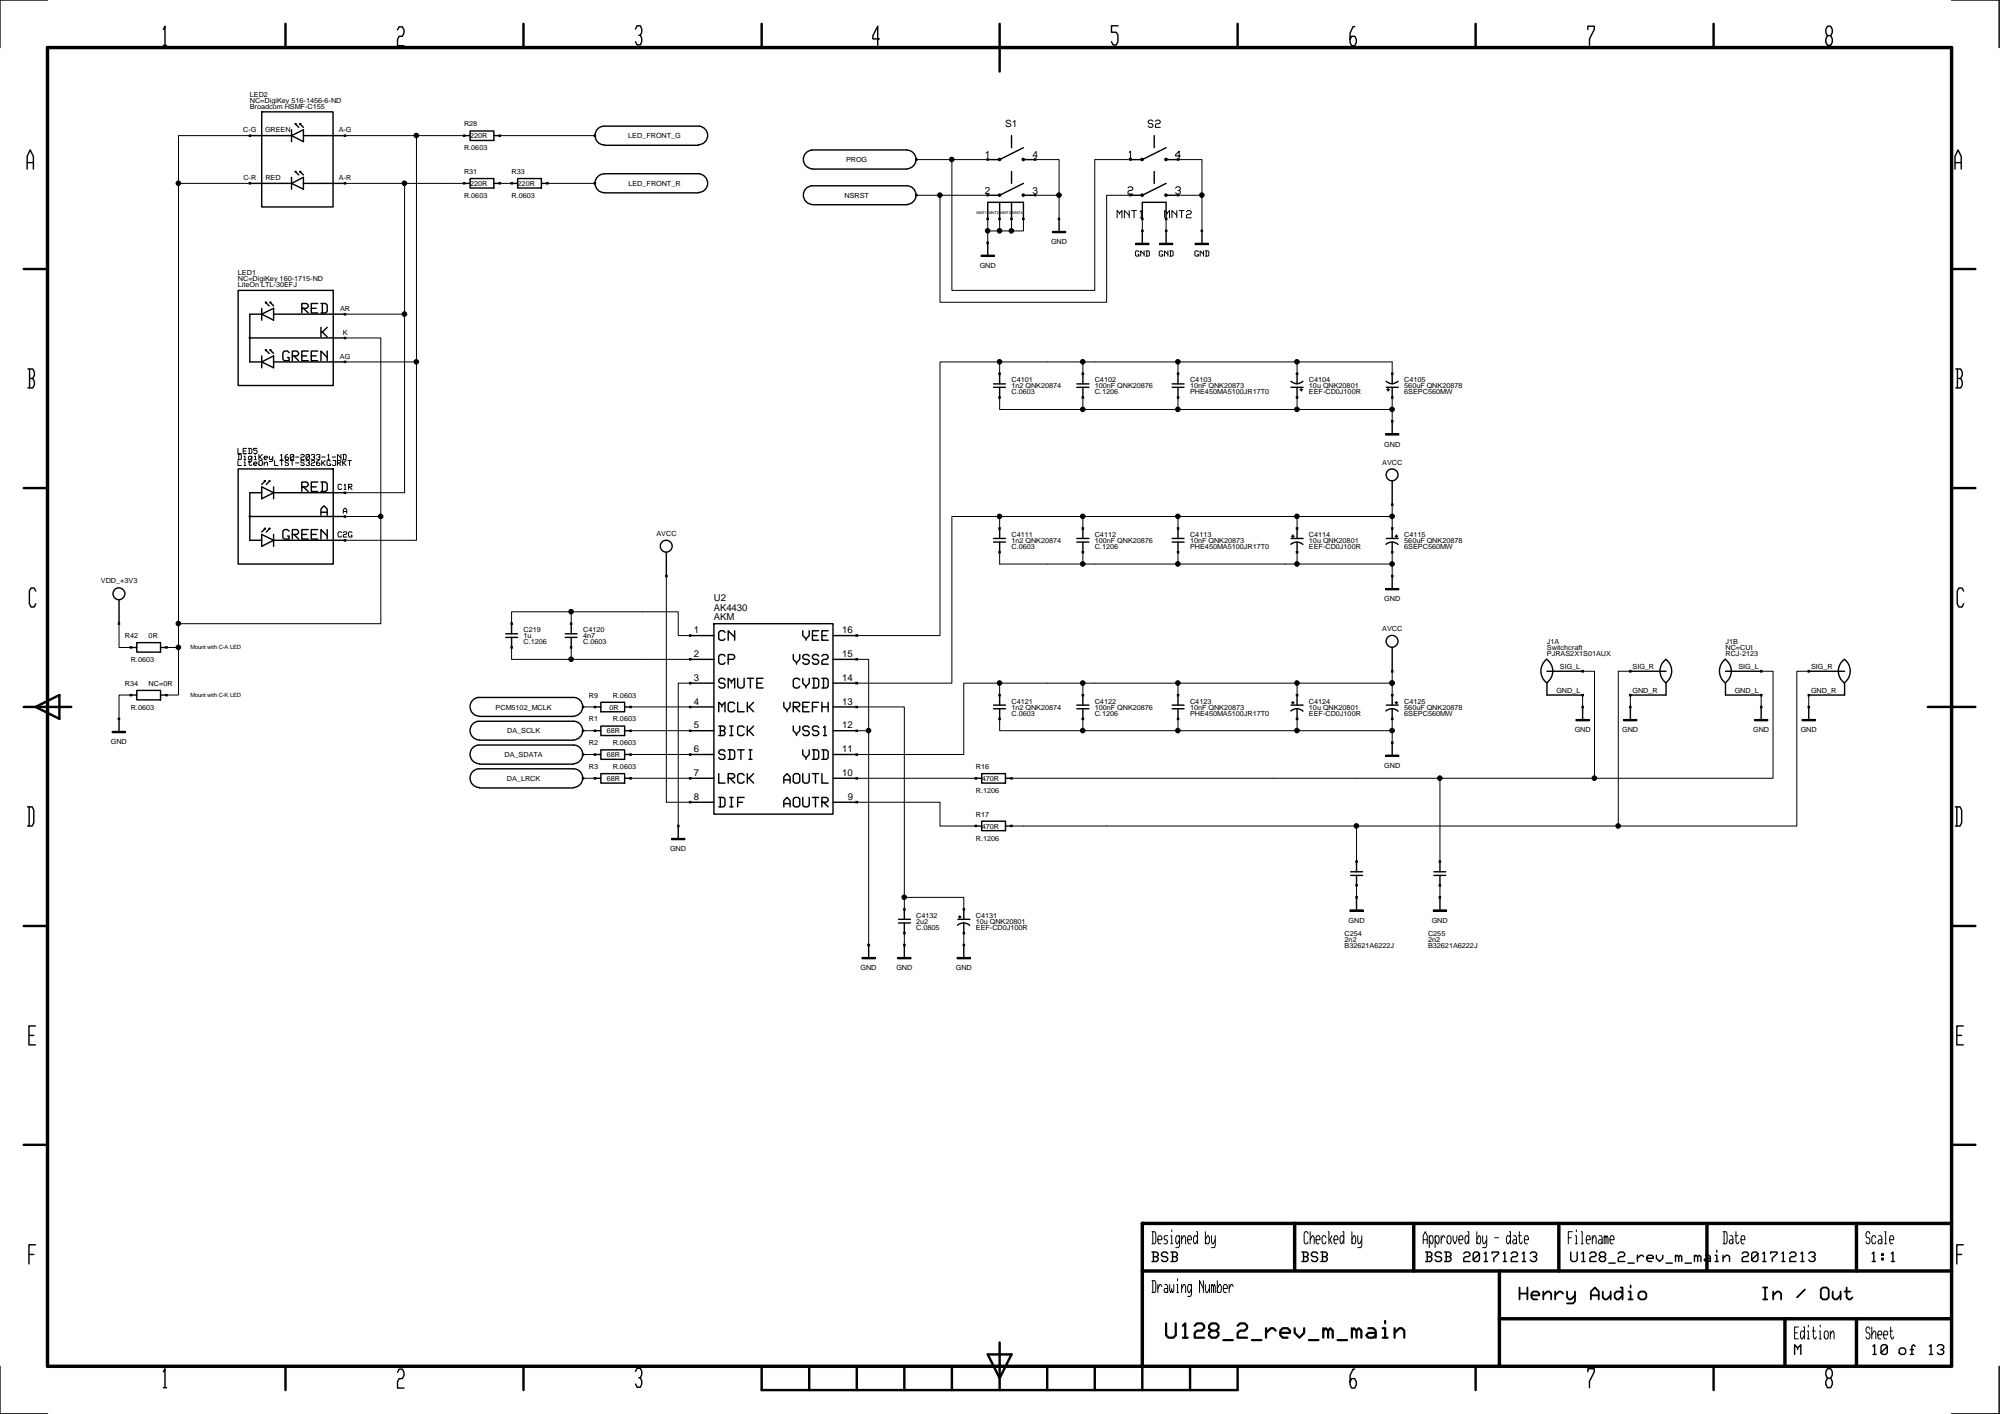
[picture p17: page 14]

LED2
Broadcom HSMF-C155 NC=DigiKey 516-1456-6-ND

LED1
NC=DigiKey 160-1715-ND LiteOn LTL-30EFJ

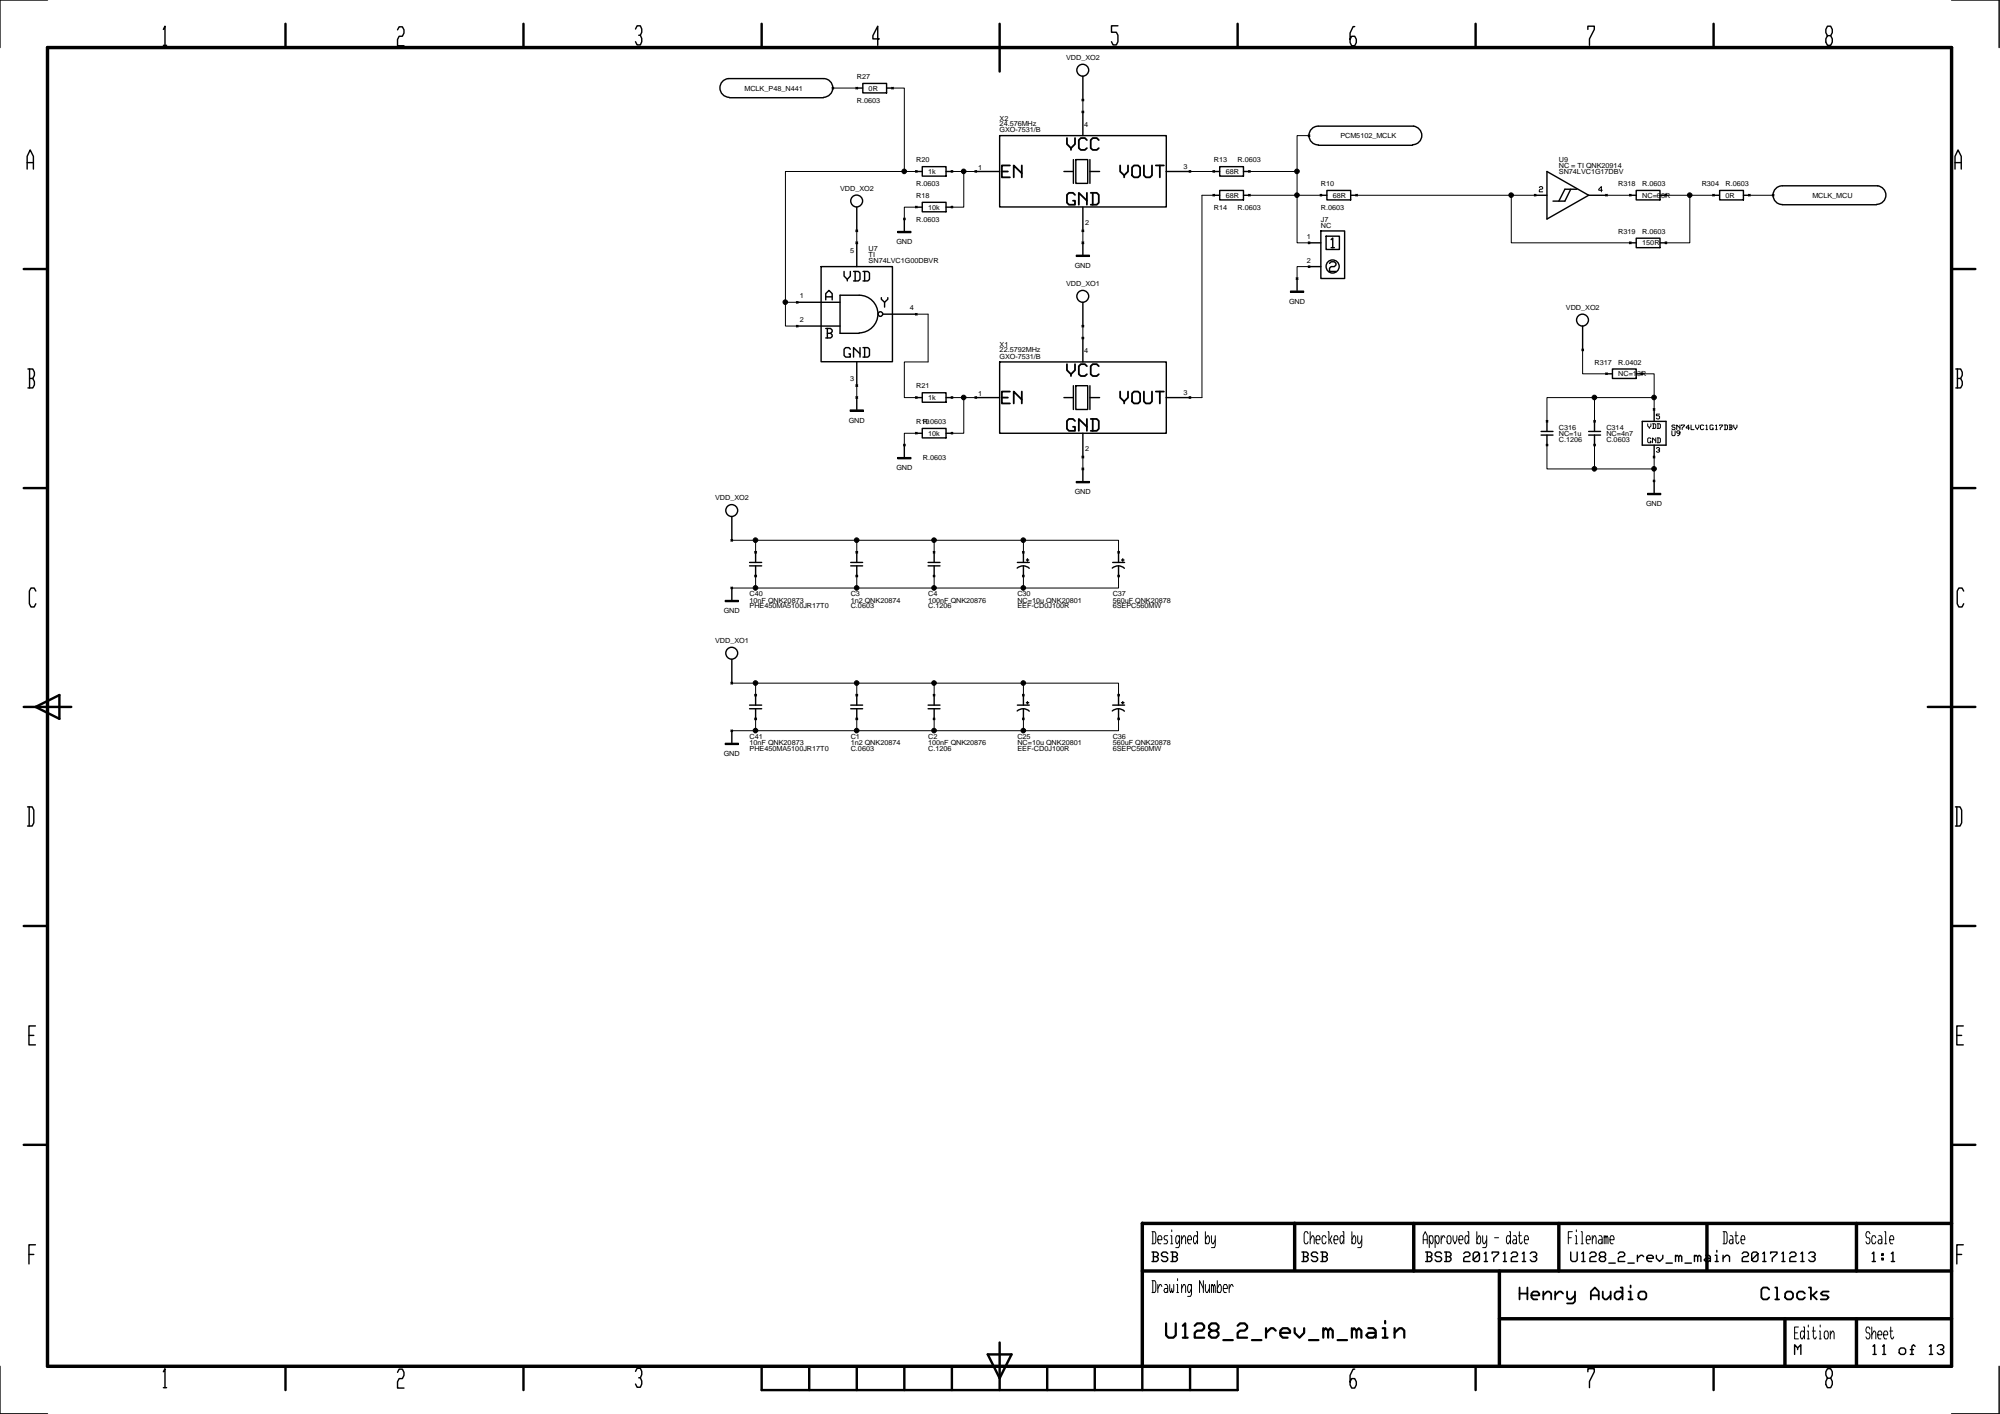
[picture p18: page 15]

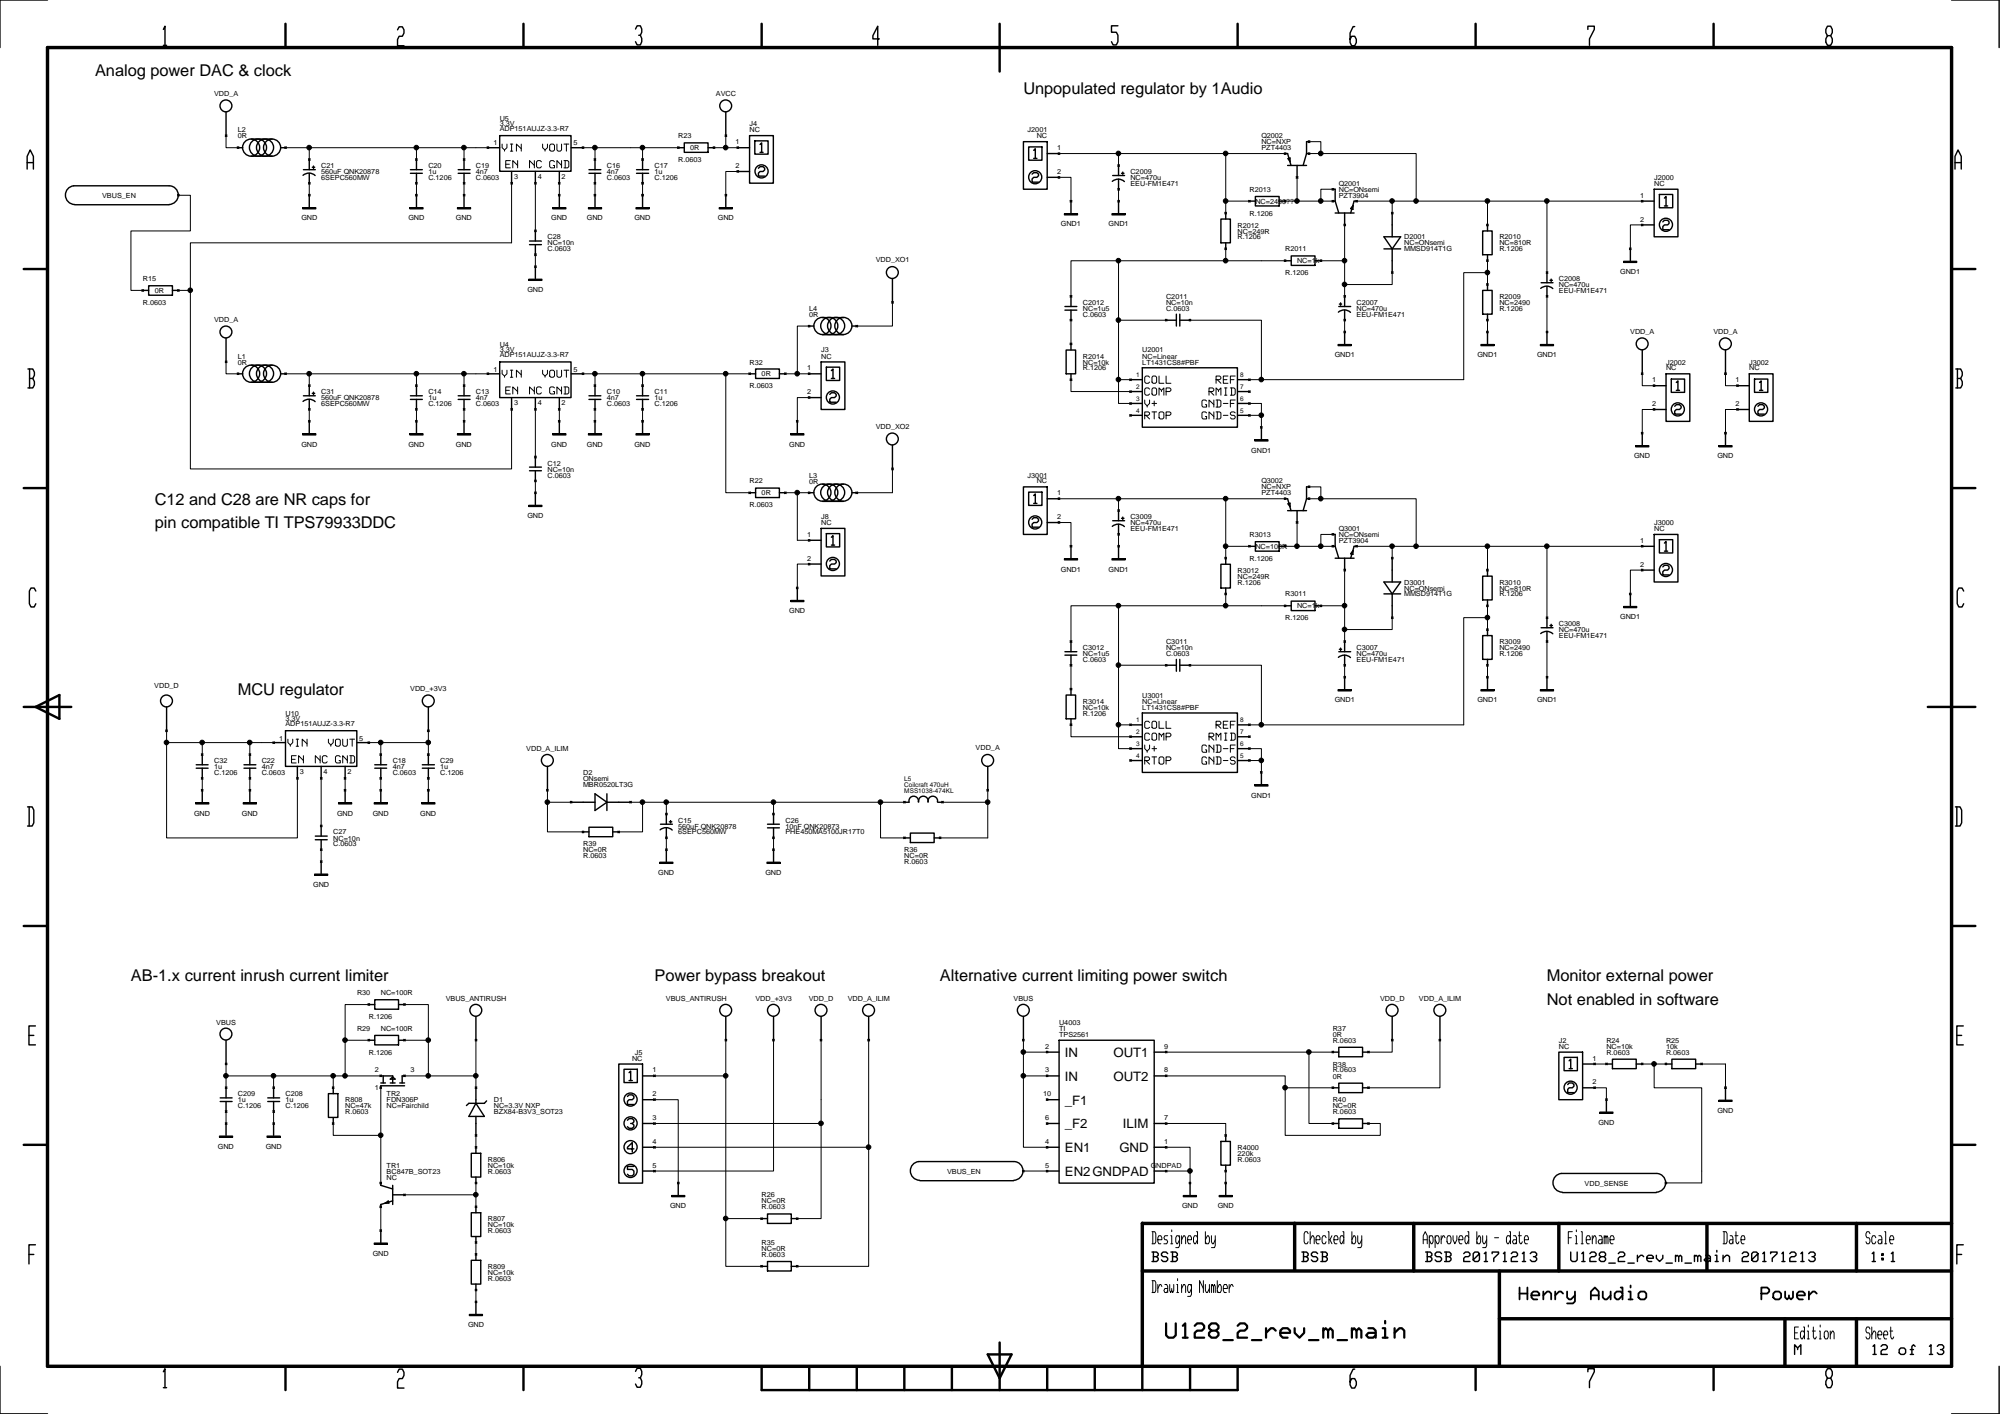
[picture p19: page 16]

Analog power DAC & clock

C12 and C28 are NR caps for
pin compatible TI TPS79933DDC

Monitor external power
Not enabled in software

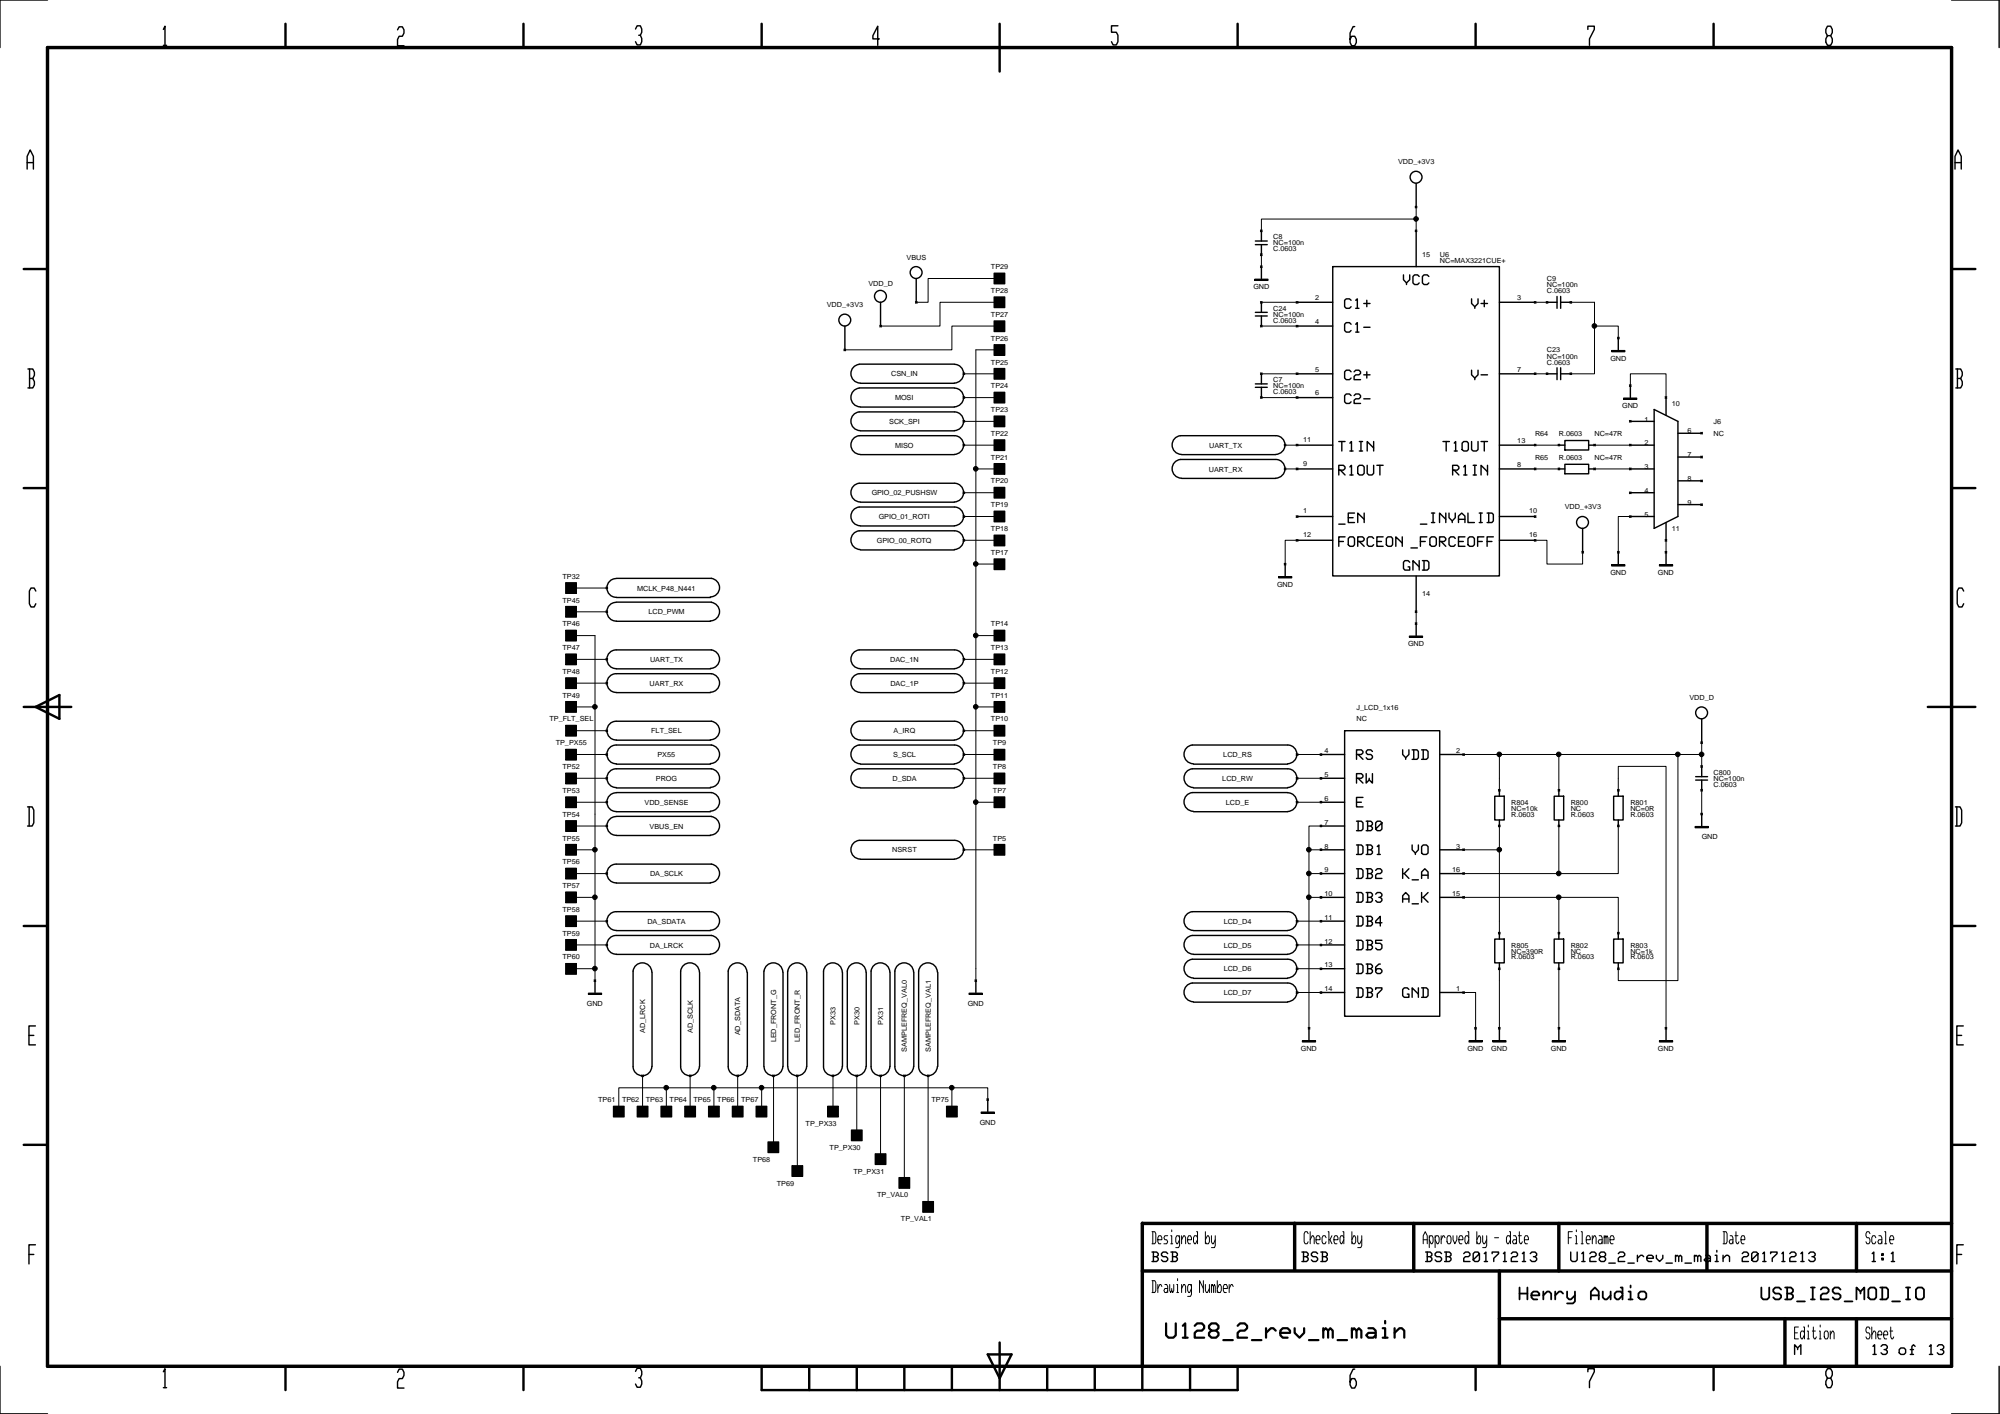
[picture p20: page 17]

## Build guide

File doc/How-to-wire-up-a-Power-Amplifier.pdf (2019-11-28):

# How to Wire up an Audio Power Amplifier for Zero Noise Problems

# www.hifisonix.com

### Andrew C. Russell

V+

### Transformer

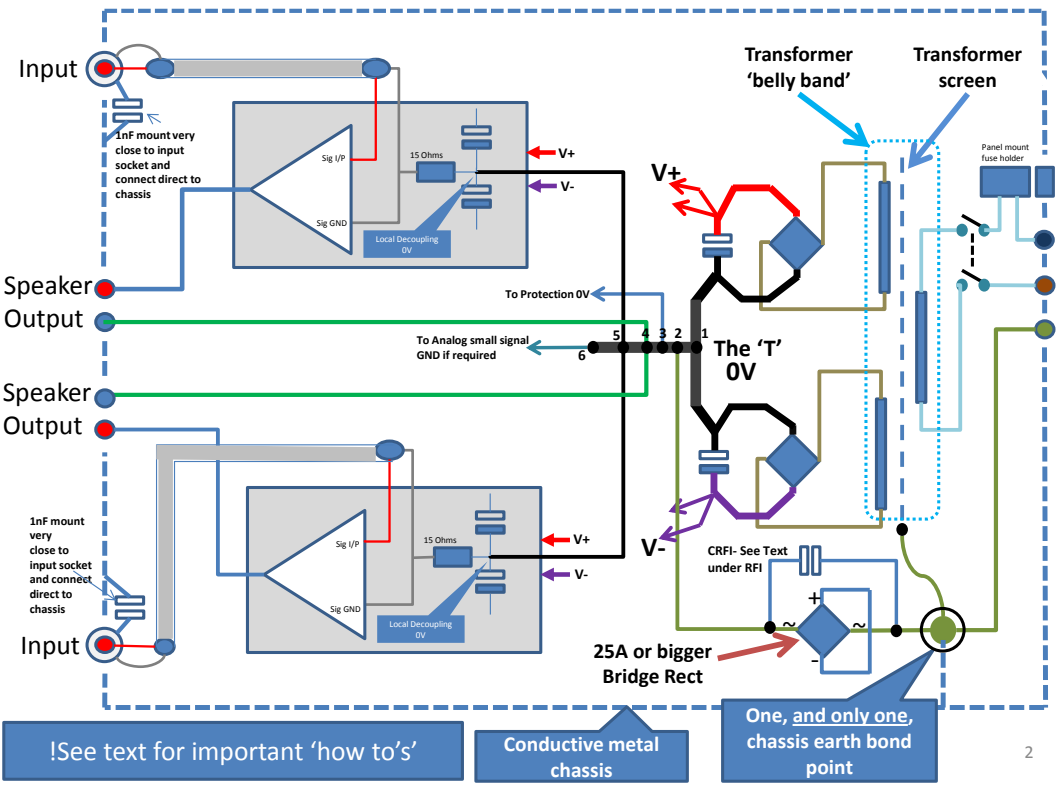
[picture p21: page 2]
The ‘T’; 15 Ohms; Local Decoupling 0V; Sig GND; Sig I/P; screen; Panel mount fuse holder; Input; Speaker Output; 25A or bigger Bridge Rect; 1nF mount very close to input socket and connect direct to chassis; Conductive metal chassis; Transformer ‘belly band’; To Protection 0V

1nF mount very
close to input
socket and
connect direct to
chassis

To Analog small signal
GND if required

CRFI- See Text
under RFI

One, and only one,
chassis earth bond
point

!See text for important ‘how to’s’

# Achieving ‘Zero Noise’ is Easy if You Follow These Basic Rules

## - Mains wires to the fuse, switch and to the transformer primary are tightly twisted* together

- Transformer wires from each secondary to its associated bridge rectifier are tightly twisted

## together

- Wires from each bridge rectifier to their associated filter capacitor(s) are tightly twisted

## together

- The V+, V- and 0V to each of the amplifier boards are twisted tightly together. These wires

## come directly off the filter capacitors – note carefully how this is drawn in the diagram

- Keep the speaker output wire from the amplifier board to the output terminal as short as

## practical

- Keep the speaker return wire from the speaker socket back to the ‘T’ as short as possible. Ideally, you should twist the speaker + and – cables together, but this is usually difficult in practice due to layout limitations.
- There is only ONE and only ONE chassis bond point in the amplifier – multiple bond points run the risk of creating earth loops. Make sure it’s a high quality connection – use serrated washers and lock nuts and ensure they are tight. Use a meter to check that all parts of the metal chassis connect to this bond point.

## - The input or output sockets may NOT make any direct connection to the metal chassis - Keep high current wires away from small signal wires

### * Twin wires also work, though not as well as twisting

# How to Order the ‘T’ – its Important for Low Noise

# - Note carefully the order to the ‘T’ section – from right to left on the diagram

## 1. filter capacitor junction 2. Take off point to earth bond connection 3. Any protection circuits or digital signal boards 4. Speaker returns – these are high current 5. Decoupling and small signal Amplifier module/PCB 0V 6. Any small signal analog board – e.g. preamplifier stage(s)

# - The total length of the ‘I’ in the ‘T’ need not be longer than 3~4 centimeters - Keep the top bar the T as short as possible – to do this, mount the filter caps right next to each other

- See the next page for how to do these things practically.

~

_

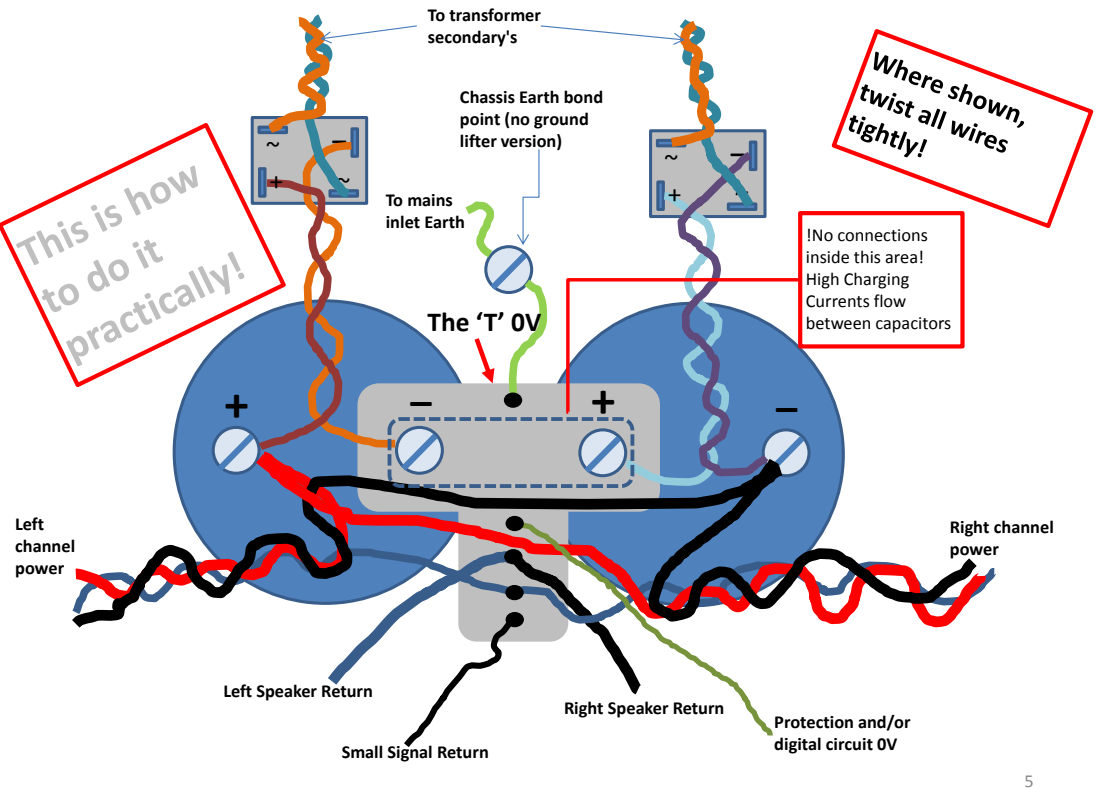
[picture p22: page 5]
Left channel power; Right channel power; To transformer secondary's; The ‘T’ 0V; To mains inlet Earth

Chassis Earth bond
point (no ground
lifter version)

!No connections
inside this area!
High Charging
Currents flow
between capacitors

Left Speaker Return

Right Speaker Return

Protection and/or

digital circuit 0V Small Signal Return

# General Rules

## - Keep input wiring away from output wiring - Keep mains wiring away from all other wiring

- Keep the secondary connections to the rectifiers and capacitors as short as possible, and away from other wiring.
- Use good quality screened cable for the input socket to amplifier board connection. Cheap

## cable simply bundles the ‘screen’ with the core and offers less than adequate protection against noise (see next page for comments on RFI). Good quality screen cable has a tight

woven screen. If you do not have screened cable, tightly twist the signal and ground wire –

## this can be very effective as well. Keep the input wiring well away from any high current wiring - Twisting the feed and return wires between transformer, rectifiers, smoothing caps and

amplifier modules minimizes the radiating area, and thus noise emissions.
- You will note a 15 Ohm resistor in the amplifier module between the signal ground and the amplifier module 0V.

– This resistor ensures that equipment plugged into the amplifier input does not cause earth loop currents to flow in the screen cable between the equipment chassis. With this arrangement, the earth currents (fault and normal leakage) are forced to flow in the earth (i.e. ground) wires. This technique is very effective in reducing hum caused by earth loops.

## - ALL equipment should have a solid chassis connection to earth/ground through the mains

earth wire. This is critical for electrical safety and is also a legal requirement.

– However, double insulated consumer equipment that only use 2 pin mains connection is typically found in North America and some Asian countries. The techniques described above work on this type of equipment as well – i.e. you can still achieve ‘zero noise’

# RFI

## - Wire 1nF ceramic capacitor from the input socket 0V to the chassis as close to the input socket as possible. This shunts RFI to ground as it enters the chassis and

prevents internal radiation, reducing susceptibility to pickup.

## - In some designs, you may get better immunity by fitting a 10nF capacitor Ccomp across the AC terminals of the ground lifer bridge rectifier. This shunts any RF on

the chassis coming in through the input cables to earth.

## - You can test your amplifier immunity once fully assembled with all the panels screwed in by placing your mobile phone on top of your amplifier and then getting a friend to call you. You should hear no buzzing or extraneous noises over

your speakers.

- Always ensure you have a band limiting filter on the input of your amplifier. 1k and 220pf is a good compromise. If you are worried about thermal noise, 220 Ohms and 1nF is also ok. But, whatever you do, make sure you have the filter - Good quality interconnects (tightly woven screen, gold plated plugs and sockets) also help prevent RFI problems

# If You Get it Right, Here Are the Results You Should Expect

# - With no inputs plugged into your amplifier, you should see no more than about 200uV pk-pk noise on the output – for a ~100W amplifier, that translates to better than -105 dB noise. If you do a really good job, you can expect half this level, or about 100uV or about -110 dB

- With a preamp plugged in and powered up with volume set to minimum,

# assuming it is correctly wired up, the noise should not exceed 500uV pk-pk – that’s still about -100 dB - With the preamp plugged in, but powered OFF, the noise level should be

-105 dB.

# Happy Listening!

# Zero Noise Audio Amplifier FAQ’s

### - I read that you need a balanced input for good noise rejection performance

– You can achieve ~-110 dB with good wiring on single ended input amplifiers. Balanced inputs are necessary in professional applications where electrical noise levels are usually much higher. For domestic applications, single ended is ample for most applications

### - Is it true that balanced inputs sound better than single ended inputs?

– We are talking about how to wire an amplifier up for lowest possible noise here. I cannot comment on the sound.

### - Why do you show a ‘screen’ on your transformer and what does it do?

– A capacitance exists between the primary and secondary of a transformer. In a toroid, it is much higher than in a E core or R core. This capacitance couples mains noise from the primary side onto the secondary. The screen is located between the primary and secondary and connects the inter-winding capacitance to GND, effectively shunting the mains noise to ground as well. This technique can deliver 20~30 dB noise reduction if executed correctly and save on the cost of the mains filter.

- What kind of mains power socket (i.e. mains inlet receptacle) do you recommend for the power inlet.
– For DIY, always use a switched, fused IEC 3PIN socket. Here is a link to a suitable one from mouser: mains entry socket (http://www.mouser.com/ProductDetail/Schaffner/FN286-10-06/) These types of sockets are safe, incorporate the very important fuse and a switch. Note, if you shop around, you can get good quality inlets for about $7.

### - What is a ‘belly band’ and what does it do?

– A belly band is a thin metal overwrap that goes around the outside of a transformer (E core or toroid). It is very effective in reducing the radiated field from the transformer, and thus in reducing noise. If your transformer is wound with a screen and a belly band, it is possible to get very good noise performance. I recommend that you always specify both if you have a transformer custom wound

- Why do you have separate rectifiers on each of the secondaries going to capacitors. What’s going on with that

### part of the circuit? Aren't you wasting a rectifier like this?

– By rectifying and smoothing and only then combining the secondaries you almost guarantee that the capacitor charging currents – which In a big amplifier can be as high as 50~100A – are kept out of the small signal ground returns through common impedance coupling. However, do also note that you must ‘T’ off as shown in page 2 to get the full benefit of this approach. If you simply connect all the wires to the top of the ‘T’ you will probably introduce noise. As a further step, you can phase the secondariesso that their fields partially cancel, reducing noise

### - How can I phase the secondaries?

– Wrap 5 turns of insulated wire around your transformer. Connect the two ends to a pair of headphones. Listen to the sound. Then swap the connections around between the secondary and its associated bridge rectifier on one of the secondaries. If the noise is louder, return the secondary connections to how they were previously, otherwise leave them as is. Its that simple.

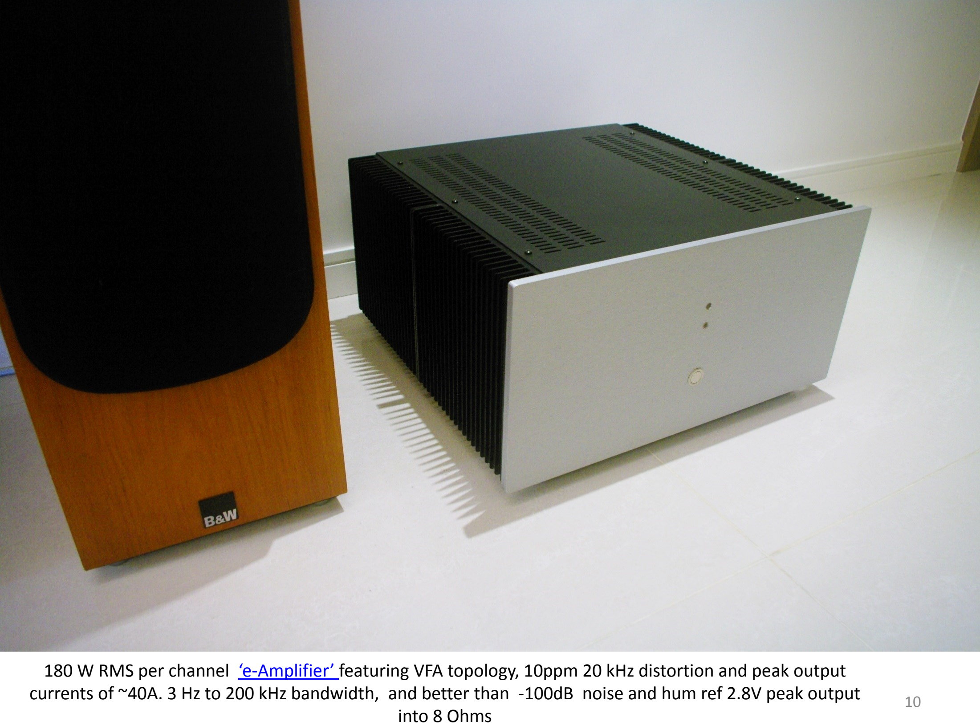
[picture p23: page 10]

180 W RMS per channel ‘e (http://hifisonix.com/ovation-e-amp/)- (http://hifisonix.com/ovation-e-amp/)Amplifier’ (http://hifisonix.com/ovation-e-amp/) featuring VFA topology, 10ppm 20 kHz distortion and peak output currents of ~40A. 3 Hz to 200 kHz bandwidth, and better than -100dB noise and hum ref 2.8V peak output

### into 8 Ohms

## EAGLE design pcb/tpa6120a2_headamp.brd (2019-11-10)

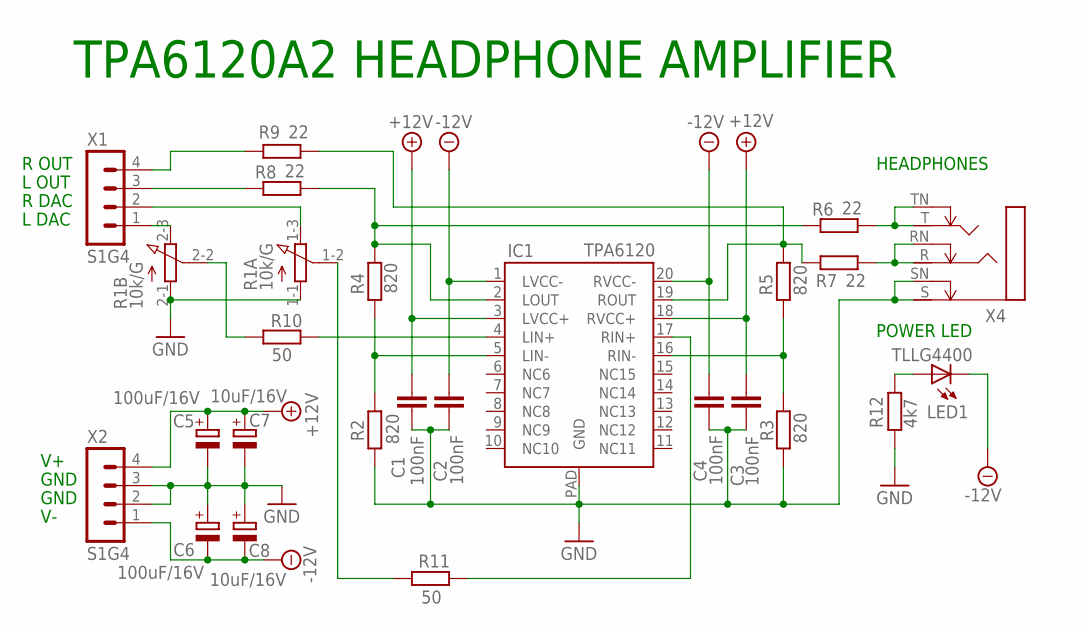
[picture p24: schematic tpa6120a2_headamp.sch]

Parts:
C1, C2, C3, C4: 100nF; C1206
C5, C6: 100uF/16V; SMC_D
C7, C8: 10uF/16V; SMC_C
IC1: TPA6120; SO20POWERPAD
LED1: TLLG4400; LED3MM
R1: 10k/G; ALPS-RK27-DUAL
R2, R3, R4, R5: 820; R1206
R6, R7, R8, R9: 22; R1206
R10, R11: 50; R1206
R12: 4k7; R1206
X1, X2: S1G4; MA04-1
X4: NMJ6HCD2

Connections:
+12V: C1.1, C3.1, C5.+, C7.+, IC1.3 (LVCC+), IC1.18 (RVCC+), X2.4
-12V: C2.1, C4.1, C6.-, C8.-, IC1.1 (LVCC-), IC1.20 (RVCC-), LED1.K (C), X2.1
GND: C1.2, C2.2, C3.2, C4.2, C5.-, C6.+, C7.-, C8.+, IC1.PAD (GND), R1.1-1 (1), R1.2-1 (1), R2.1, R3.1, R12.1, X2.2, X2.3, X4.S, X4.SN
unnamed: IC1.19 (ROUT), R5.2, R7.1, R9.2
unnamed: IC1.5 (LIN-), R2.2, R4.1
unnamed: IC1.16 (RIN-), R3.2, R5.1
unnamed: IC1.2 (LOUT), R4.2, R6.1, R8.2
unnamed: R6.2, X4.T, X4.TN
unnamed: R1.2-3 (3), X1.1
unnamed: R1.1-3 (3), X1.2
unnamed: R1.2-2 (2), R10.1
unnamed: R1.1-2 (2), R11.1
unnamed: R7.2, X4.R, X4.RN
unnamed: IC1.4 (LIN+), R10.2
unnamed: IC1.17 (RIN+), R11.2
unnamed: LED1.A, R12.2
unnamed: R8.1, X1.3
unnamed: R9.1, X1.4

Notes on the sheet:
TPA6120A2 HEADPHONE AMPLIFIER
L DAC
R DAC
L OUT
R OUT
GND
HEADPHONES
POWER LED

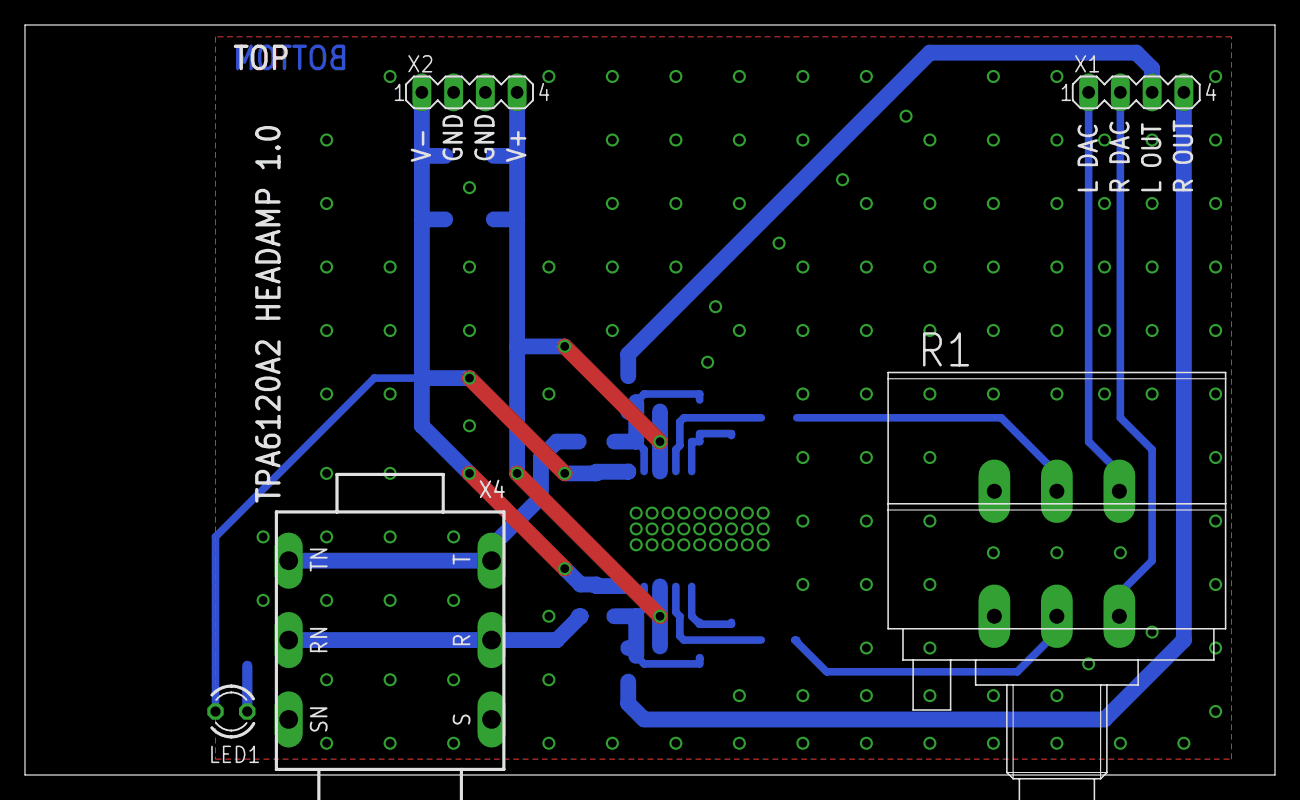
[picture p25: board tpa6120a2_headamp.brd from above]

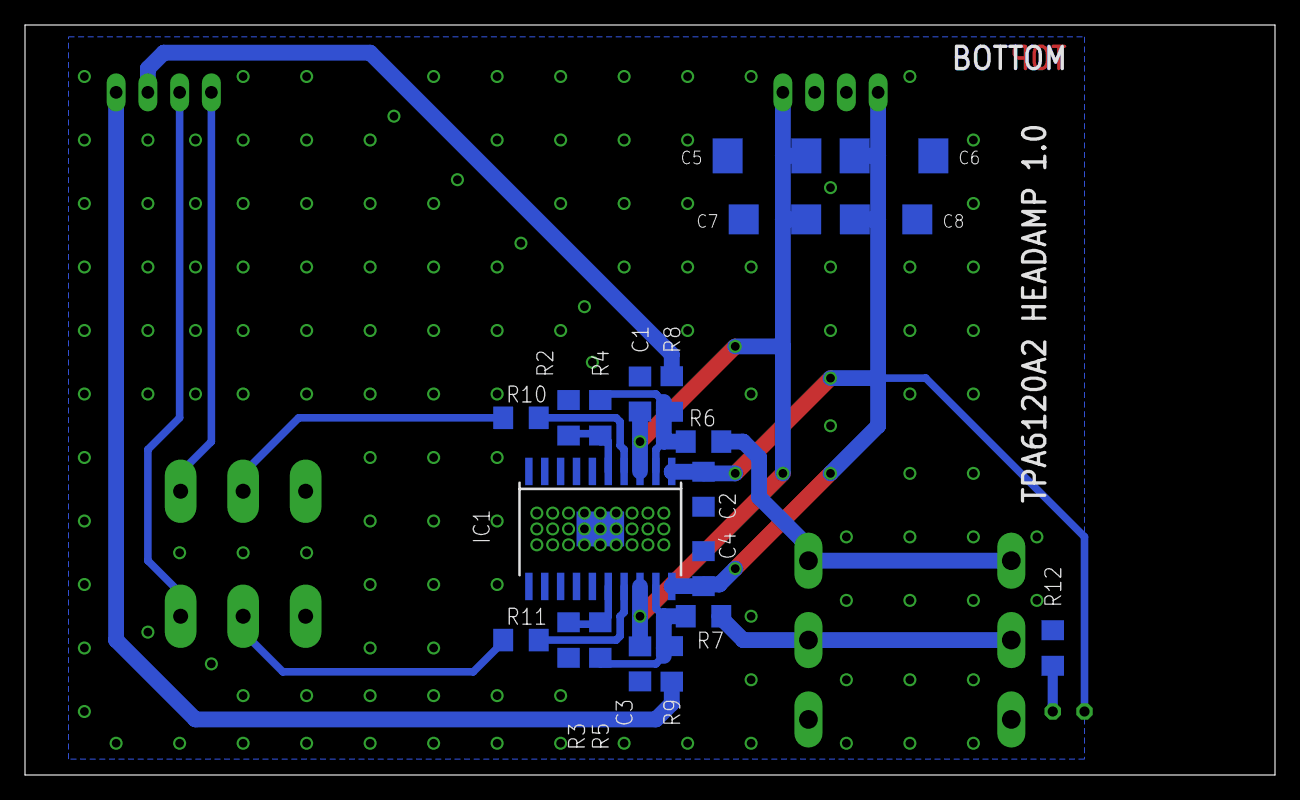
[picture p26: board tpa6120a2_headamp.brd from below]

Board: 2 copper layers, 100.0 x 60.0 mm, 25 parts (20 on the bottom side), 18 nets.

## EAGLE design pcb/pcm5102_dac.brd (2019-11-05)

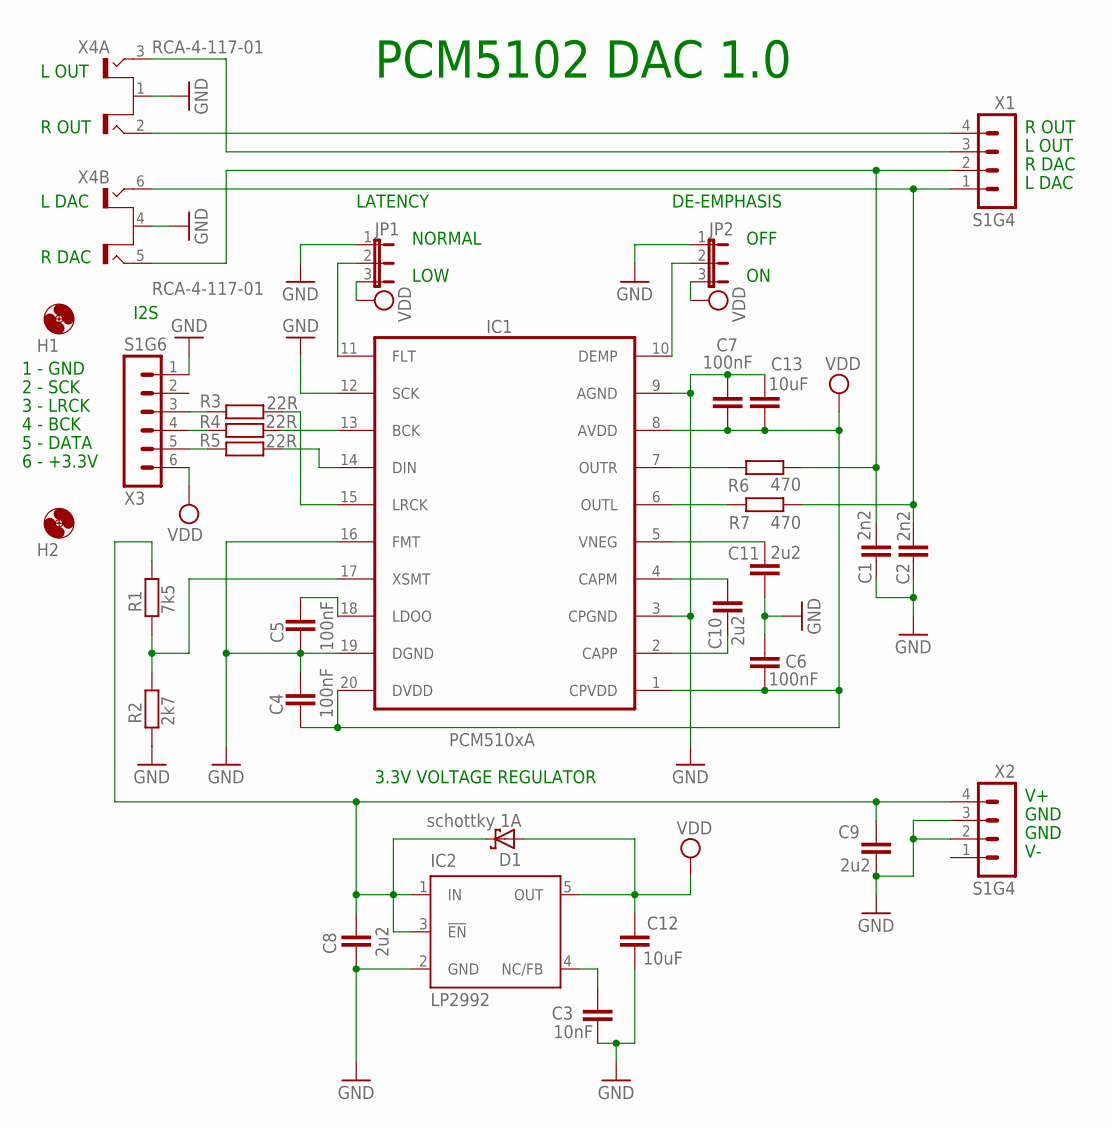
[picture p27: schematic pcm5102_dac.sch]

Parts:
C1, C2: 2n2; C1206
C3: 10nF; C1812
C4, C5, C6, C7: 100nF; C1206
C8, C9, C10, C11: 2u2; C1206
C12, C13: 10uF; C1206
D1: schottky 1A; SMB
H1, H2: MOUNT-HOLE3.2; 3,2
IC1: PCM510xA; TSSOP20
IC2: LP2992; SOT23-DBV
JP1, JP2: DIL; JP2
R1: 7k5; R1206
R2: 2k7; R1206
R3, R4, R5: 22R; R1206
R6, R7: 470; R1206
X1, X2: S1G4; MA04-1
X3: S1G6; MA06-1
X4: RCA-4-117-01

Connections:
GND: C1.2, C2.2, C3.2, C4.1, C5.2, C6.1, C7.1, C8.2, C9.2, C11.2, C12.2, C13.1, IC1.3 (CPGND), IC1.9 (AGND), IC1.12 (SCK), IC1.16 (FMT), IC1.19 (DGND), IC2.2 (GND), JP1.1, JP2.1, R2.1, X2.2, X2.3, X3.1, X4.1 (S), X4.4 (S)
LDOO: C5.1, IC1.18 (LDOO)
unnamed: R5.1, X3.5
unnamed: C8.1, C9.1, D1.C, IC2.1 (IN), IC2.3 (!EN), R1.2, X2.4
unnamed: X1.3, X4.3 (T2)
unnamed: C3.1, IC2.4 (NC/FB)
unnamed: IC1.17 (XSMT), R1.1, R2.2
unnamed: X1.4, X4.2 (T1)
unnamed: C2.1, R7.2, X1.1, X4.6 (T2)
unnamed: R3.1, X3.3
unnamed: R4.1, X3.4
unnamed: IC1.13 (BCK), R4.2
unnamed: IC1.14 (DIN), R5.2
unnamed: IC1.11 (FLT), JP1.2
unnamed: IC1.10 (DEMP), JP2.2
unnamed: IC1.15 (LRCK), R3.2
unnamed: C10.1, IC1.4 (CAPM)
unnamed: C10.2, IC1.2 (CAPP)
unnamed: C11.1, IC1.5 (VNEG)
unnamed: IC1.7 (OUTR), R6.1
unnamed: IC1.6 (OUTL), R7.1
unnamed: C1.1, R6.2, X1.2, X4.5 (T1)
VDD: C4.2, C6.2, C7.2, C12.1, C13.2, D1.A, IC1.1 (CPVDD), IC1.8 (AVDD), IC1.20 (DVDD), IC2.5 (OUT), JP1.3, JP2.3, X3.6

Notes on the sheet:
1 - GND
2 - SCK
3 - LRCK
4 - BCK
5 - DATA
6 - +3.3V
I2S
PCM5102 DAC 1.0
R OUT
L OUT
R DAC
L DAC
GND
NORMAL
LOW
DE-EMPHASIS
LATENCY
OFF
3.3V VOLTAGE REGULATOR

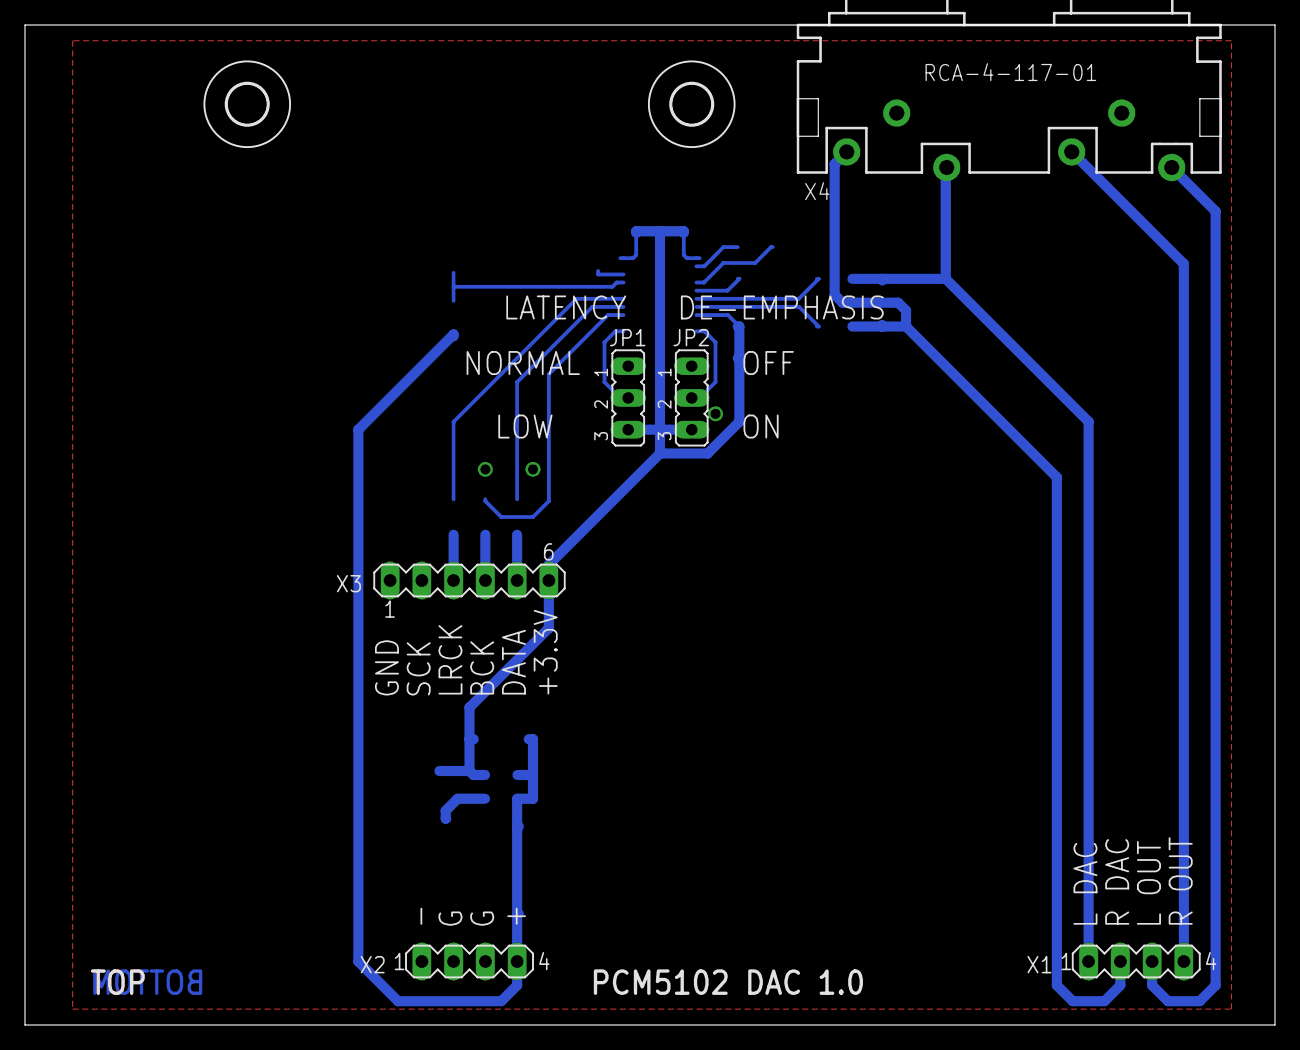
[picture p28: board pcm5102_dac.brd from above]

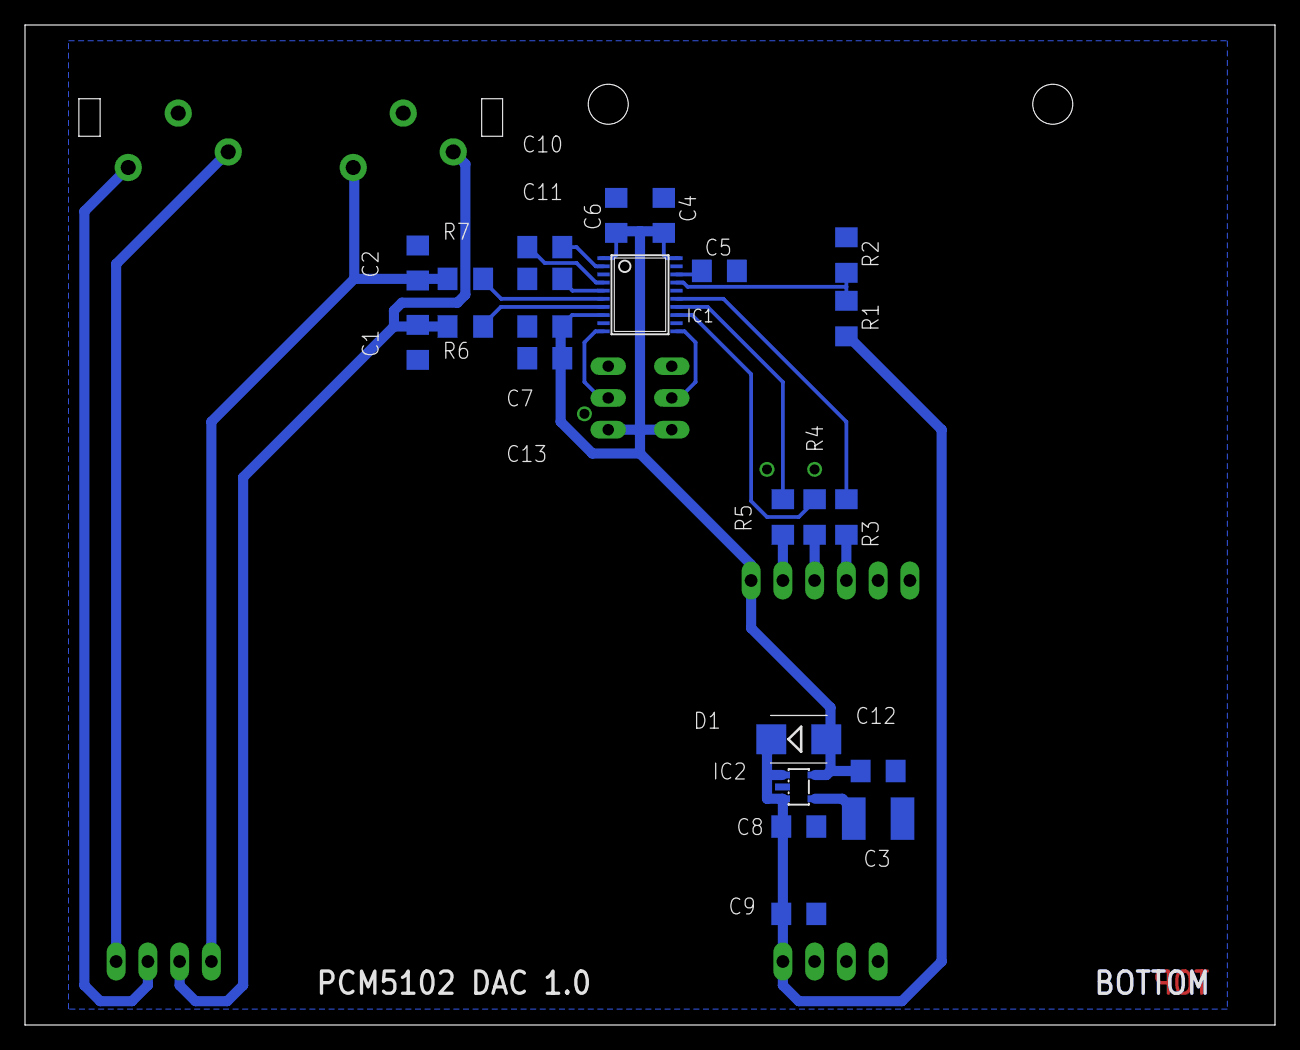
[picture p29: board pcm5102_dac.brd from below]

Board: 2 copper layers, 100.0 x 80.0 mm, 31 parts (23 on the bottom side), 23 nets.

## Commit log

2019-11-05 added dac schematic
    [pcm5102_dac.sch]
2019-11-05 added dac pcb design
    [pcm5102_dac.brd]
2019-11-10 added headphone amp pcb design
    [tpa6120a2_headamp.brd]
2019-11-10 added hedphone amp schematic design
    [tpa6120a2_headamp.sch]
2019-11-23 Working interface...yikes :)
    In this photo the interface is working only on DAC outputs,because i need to design a power supply for the amplifier for fully working mode (the dac outputs overrides the amplifier right now).
2019-11-28 dac case format
2019-11-29 added schematic for power supply
    [sursa alimentare.sch]
